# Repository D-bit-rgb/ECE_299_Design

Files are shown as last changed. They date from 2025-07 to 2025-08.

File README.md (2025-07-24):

# ECE 299 Final Project – FM Clock Radio Prototype

This repository contains the full documentation, code, schematics, and PCB layouts for a custom FM Clock Radio designed as the final submission for the ECE 299 course at the University of Victoria.

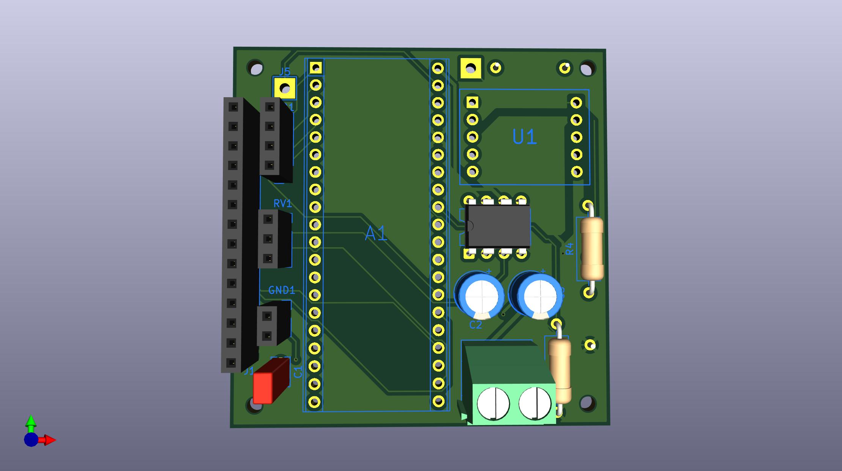
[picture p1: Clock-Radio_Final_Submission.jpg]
Final PCB Design


---

## 📻 Overview

The FM Clock Radio combines an embedded microcontroller, a digital FM tuner, and a custom-designed PCB to create a functional prototype. The device is powered by a Raspberry Pi Pico running MicroPython, enabling station tuning, audio output, and modular interfacing.

The final product includes:

- FM radio functionality via I2C
- Custom PCB designed in KiCAD
- Schematic documentation
- 3D printable housing (prototype stage)
- Expandability for clock/alarm integration

---

## 📁 Repository Structure

```bash
.
├── .vscode/                        # VSCode workspace settings
├── .micropico/                    # MicroPython config for Pico
├── Clock-Radio/                   # Final PCB folder (KiCAD files)
├── Clock-Radio_Final_Submission.jpg  # Image of final PCB layout
├── Clock-Radio_Prototype.jpg      # Render of 3D enclosure/prototype
├── ECE299_SCHEMATIC.pdf           # Main schematic overview
├── fm_radio.py                    # MicroPython FM radio driver
├── fm_radio (1).py                # Backup or variant of the radio code
├── Radio.kicad_pro                # KiCAD project file
├── Radio.kicad_sch                # Main circuit schematic (KiCAD)
├── Radio.kicad_pcb                # Final PCB layout (KiCAD)
├── Radio_Schematic_1.pdf          # Amplifier or supporting circuits
├── Radio_schematic_2.pdf          # Additional subsystems
├── Sheet1.SchDoc                  # Altium schematic (legacy or alternate)
├── LICENSE                        # MIT License
└── README.md                      # This file

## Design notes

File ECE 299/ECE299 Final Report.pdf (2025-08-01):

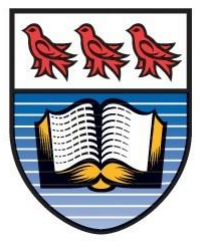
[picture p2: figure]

# ECE 299 Group 8 Final Project Report

## Daryon Ambasse – V01034226

## Rowyn Davis - V01038276

## Aug 2, 2025

# Executive Summary

This report outlines the ECE 299 final design project completed by students Daryon Ambasse and Rowyn Davis from May to August 2025. The course introduces students to the engineering design process through a term-long hands-on project, emphasizing planning, prototyping, testing, and documentation.

The project objective was to develop a functional clock radio system using a Raspberry Pi Pico W, programmed in Micropython. All time and radio data had to be displayed using dual SPI OLED screens, and a 2-layer custom PCB was required. The final product included a digital clock, alarm system, FM tuner, volume control, and world time zone viewer.

Key hardware components:

- Dual 128×64 OLEDs acting as one 256×64 display via SPI.
- FM radio receiver module (I²C-controlled).
- Alarm and snooze system with persistent flash storage.
- Amplifier and speaker system with volume potentiometer.
- 4 tactile buttons for user interaction across 5 modes.
- Custom 2-layer PCB with 0.6 mm traces for higher current paths.
- SolidWorks-designed 3D-printed enclosure with all I/O on one edge.

Software features included five interactive modes: clock display, radio interface, alarm setting, system info (12/24hr toggle), and time zone switching. The system used edge-detection for button presses, persistent JSON-based settings storage, and clean display updates in real time.

Throughout development, students learned soldering, PCB design, safe tool use, audio system optimization, and team-based project execution. Challenges such as broken displays, pin damage, and enclosure misfits were resolved through iterative testing and repair.

The project was delivered on time, under a $63.26 budget, and met all technical and functional requirements. It demonstrates practical application of embedded systems design, teamwork, and engineering professionalism aligned with EGBC standards.

## Table of Contents

# List of Tables

Table Number Title | Page number
Table 1 | Team Member 1, tasks and deliverables | 9
Table 2 | Team Member 2, tasks and deliverables | 10
Table 3 | Bill of Materials for entire project | 13

# List of Figures

Figure Number Title | Page number
Figure 1 | PCB Schematic | 12
Figure 2 | PCB editor layout in KiCAD | 15
Figure 3 | 3D PCB front view in KiCAD | 16
Figure 4 | 3D PCB back view in KiCAD | 17
Figure 5 | 3D Lid Back View in SolidWorks | 18
Figure 6 | 3D Lid Front View in SolidWorks | 18
Figure 7 | 3D Bottom Back View in SolidWorks | 19
Figure 8 | 3D Bottom Front View in SolidWorks | 19
Figure 9 | Lid Drawing in SolidWorks | 19
Figure 10 | Bottom Enclosure Drawing in SolidWorks | 19
Figure 11 | Terminal Output from button test in Appendix D | 21
Figure 12 | MP4 file of the speaker output using the radio test file in Appendix F (channel frequency 98.5) | 22
Figure 13 | Dual OLED test display as per Appendix E | 23

# Project Goals

The project goals that were agreed upon include:

1. Implement battery power using AA batteries to power the operation of the clock-radio system.
2. Enable user-adjustable clock and alarm settings, including the option to display alternate time zones.
3. Incorporate a snooze feature.
4. Provide intuitive FM radio channel selection through accessible user input.
5. Clear audio playback from a compact onboard speaker.
6. Display all relevant system information—including time, alarm status, FM channel, snooze, and alternate time zones—across two OLED screens using SPI communication.
7. Have an animal themed aesthetic by integrating a stuffed animal as the exterior.

8. Develop a structural “skeleton enclosure” using SolidWorks to support internal components and maintain structural stability.
9. Design a compact (<30 cm²) 2-layer PCB in KiCad that integrates both the Raspberry Pi Pico W and the audio amplifier circuit.
10. Utilize a maximum of four buttons and one potentiometer to manage all user interface settings and volume control.

# List of constraints

The constraints that were set out by the students and Prof. Ilamparithi Thirumarai Chelvan are as follows [2]:

1. Design and assemble the final clock/radio by July 29, 2025.
2. Only 1 Raspberry Pi Pico W is to be used as the microcontroller for all handling. Must be programmed with Micropython.
3. The clock displays radio and clock information. Communicates with the Raspberry Pi through SPI protocol.
4. The radio communicates with the Raspberry Pi through I2C protocol.
5. Design and manufacture an animal themed enclosure.
6. Team members must be from the same lab section.
7. Submit the final report by August 2, 2025.
8. This project will cost the students money.

# Project Expectations

The expectations set out for this project [2]:

1. Project Expectations:
a. Design and order a 2-layered PCB with a maximum footprint of 30cm².
b. Design and assemble an enclosure using SolidWorks.
c. Solder all the components to the ordered PCB.
d. Present the clock/radio in an animal themed/enclosure.
e. Display the finished project on July 29, 2025.
2. Clock/Alarm Expectations:
a. Be able to set clock/alarm time through user interface, either hardware (i.e., buttons) or software (i.e., a website).
b. Display time in 12- or 24- hour format.
c. Have the capability of displaying different time zones through hardware or software user interface.
d. Be able enable/disable the alarm through user interface.
e. Be able to set a snooze button for the alarm.
3. Radio Expectations:
a. Be able to tune to local FM radio channels through a user interface.

b. Play audio output through a speaker.
c. Be able to control the volume through a user interface.
d. Display the radio channel information to the user.

# Design Choices

1. Project Design Choices:
a. 2-layer PCB: The team chose to use a 2-layer PCB in KiCad with the dimensions of 5.45cm x 5.49cm (29.92cm²). Using a 2-layer design allowed us to solder components on both sides of the board, effectively doubling the usable surface area. This improved the design flexibility and helped support components being placed closer together. Using a 4-layered board would increase the advantages of the 2 layered board by allowing more dense traces to save more room, however, according to Texas Instruments “PCB Design Guidelines For Reduced EMI”, 2-layer boards can achieve 95% of the effectiveness of 4-layer boards so long as [3];
- Ground is routed underneath power.
- Grid power and ground but be careful to not create unneeded common impedance connections.
- Length-to-width ration should not exceed 3:1 for any traces between IC and ground voltage.
- Under the microcomputer (i.e., the Raspberry Pi Pico W), build a solid ground plane to limit the noise. (this couldn’t be done without compromising the <30cm² constraint).
- Route returns for direct connections to the processor I/O directly under the signal trace.
b. SolidWorks Enclosure Design: The enclosure was designed in SolidWorks to fit the electrical components (Raspberry Pi, PCB, Batteries… etc.) as well as mount the buttons and OLED screens. When designing the enclosure following the 3D-printing design rules set by HYDRA RESEARCH [4]. These include but are not limited to:
- Not having horizontal bridging no longer than 10mm without vertical supports,
- R > 4mm for base corner rounding,
c. Component Soldering: All through-hole components are soldered by hand using a temperature-controlled soldering iron, following the Kester Soldering process [5]:
- Apply heat to through-hole & component pin.
- Apply solder to through-hole & component pin.
- Remove solder first after a small drop has melted into the connection and then remove heat last.
d. Present the clock/radio in an animal themed/enclosure: According the set ECE299 project constraints [2], the clock/radio enclosure needs to be in an animal shape.
e. Display the finished project on July 29, 2025: According the set ECE299 project constraints [2], presentation of the finished clock/radio to the professor and lab TA will be conducted during the last week of labs (July 29, 2025, for Rowyn Davis and Daryon Ambasse).
2. Clock/Alarm Design Choices:
a. Be able to set clock/alarm time through user interface: Using the maximum allowed number of buttons, the team created an intuitive UI that allowed users to change the time for either the clock or alarm by having using the following buttons as specified:
- Button 1: Button 1 allowed for the change of “modes”. These modes included set time and set alarm. In each mode, the use of the following buttons changed.
- Button 2: Button 2 allowed for the change of either hour or minutes in the Set Time mode or enable/disable alarm function in the Set Alarm mode.
- Button 3: Button 3 added +1 to either the hour or minute in the Set Time mode and +1 hour in the Set Alarm mode.
- Button 4: Button 4 subtracted -1 from either the hour of minute in the Set Time mode and +1 minute to the Set Alarm mode.
b. Display time in 12- or 24- hour format: By cycling to “mode 3” titled “Info” the user can activate button 4 to switch between 12 to 24-hour formatting. The process works in the following way:
- Program reads the current set time and applies a modulo factor of twelve to the current hour.
- Check if the remainder is zero; if so, replace it with 12 (i.e., midnight or noon is displayed as “12” instead of “0”).
- Determine whether to display “AM” or “PM” by checking if the original hour is less than 12 (AM) or 12 or greater (PM).
- Display the formatted time with an “AM” or “PM” suffix if in 12-hour mode, or without suffix if in 24-hour mode.
- Save the user’s display format preference (12hr or 24hr) in settings. Json so the clock remembers it after reset or power loss.
- The setting toggles every time the select button is pressed while in mode 3, updating both the display and the saved file.
c. Displaying different time zones: By cycling to “mode 5”, titled “Time Zone”, the user can activate button 4 (select) to cycle through every global time zone from UTC−12 to UTC+14 (including half-hour and 45-minute offsets). The process works in the following way:
- A predefined list of tuples stores all 39 time zones in the format ("UTC±X", offset_in_minutes).
- When the user presses the select button in mode 5, a counter (tz_index) is incremented and wrapped around when it exceeds the list length.
- The current local time (set manually in time_set mode) is retrieved and converted to a UNIX timestamp.

- The program adds the selected offset (in minutes × 60 seconds) to the timestamp to simulate that time zone.
- The updated timestamp is passed to local_time () to format it into a readable time structure.
- The formatted time (respecting 12/24-hour display setting) is shown on the dual OLED screen along with the label (e.g., “UTC+5:30”).
- The selected time zone does not change the actual internal clock — it is purely for viewing other world clocks.
- When the device resets, it starts at the default time zone (usually UTC+0), unless extended to save the last used tz_index.
d. Be able to enable/disable the alarm through user interface: When the alarm is set using “mode 2” and activated, it will go off at the designated time and can be disabled or snoozed by user input. The process works in the following way:
- The user enters mode 2 and uses buttons 1 and 2 to set the desired alarm hour and minute values.
- Button 4 toggles the alarm between ON and OFF states. A visual confirmation is shown on the screen (e.g., “Alarm On”).
- The alarm settings are saved to a persistent file (settings. Json) so they remain after power loss or reset.
- In the main loop, the current time is compared with the stored alarm time once per second.
- When the time matches and the alarm is ON, alarm_active is set to True, and a visual notification (flashing display and message) begins.
- If the user presses button 4 (select) while alarm_active is True and the system is in mode 0 (default time mode), the alarm is deactivated for that session (i.e., alarm_active = False).
- Alternatively, a snooze function may delay the alarm by 5–10 minutes (if implemented with button 3, for example).
- The alarm will not trigger again until the time is set forward again, or the device is restarted (depending on snooze implementation).
e. Be able to set a snooze button for the alarm: While the alarm was on, users could press button 2 to start the snooze duration. How long the snooze lasted for could be set by the user by going to the Snooze mode (using button 1) and selecting anywhere from 0-30 mins.
3. Radio Design Choices:
a. Be able to tune to local FM radio channels through a user interface: Modifying the provided code from Exp. 3 [6], the team managed to connect and select specific channels.
- Using buttons 3 & 4, users could go up (+0.2MHz) or down (-0.2MHz) in frequency.

- The radio frequency would be displayed on modes “Change Radio” and “Clock”.
b. Play audio output through a speaker: Using the audio amplifier circuit in combination with RDA5807M module, LM386-4 audio amplifier, and I2C protocol, the received FM radio input was outputted to the 8Ω, 0.5W speaker.
c. Be able to control the volume through a user interface: Using a 0-200Ω potentiometer to control the input voltage from the Raspberry Pi to the audio amp circuit. This gives direct control from the user to the radio.
d. Display the radio channel information to the user: Using the code from Exp. 3 [7], users were able to display and play the wanted FM-radio (i.e., 101.9) to the OLED screen.

# Project Planning

The original project planning milestone designated team members roles and designations split between hardware and software, table 2 “Roles and Responsibilities” [2] shows the initial expectations of all members. these initial conditions laid the groundwork for assigning tasks based on team members skills and responsibilities. As per the project milestone report [2], team members set deliverable dates to complete the above tasks including testing and correcting the user experience. The following table demonstrates an accurate model of the tasks completed by team members and the effective date of delivery.

Team member 1: Daryon Ambasse
Task | Testing model | Date of delivery
Wire and test the FM receiver with a single button input. | Upload the provided radio initializer file from “Lab 3” [6] adding button capabilities to change the frequency by a factor of ±0.2MHz. Then updating the model to change volume on each button press. | June 12, 2025
Design and Manufacture PCB | Design the PCB to include: • Radio and Amplifier circuit with external speaker connection to the mounted 2 Position PCB Terminal Block. • External connection ports for dual-OLED screens. • External 5-volt power connections for proper distribution to V-BUS and V-SYS on the Raspberry Pi Pico W. • External connection points for four micro-pushbuttons. • Proper M3 sized holes for mounting on the enclosure. Upon completion of the design, fully test it on a breadboard to determine points of weakness or shorting in the circuit. | July 2, 2025
Build LM386 Amplifier circuit using KiCAD. | Design the amplifier circuit in KiCAD then verify using a breadboard. Confirm audio quality in ELW | July 25, 2025

| building to record how the signal is affected in a Faraday Cage, extend antennae accordingly to capture the frequency 101.9.
Provide initialization file to accommodate for an extended OLED screen using two smaller screens. | Use a daisy-chain method for shared MOSI and MISO connections to the screens with separate Chip select pins, creating an extended display. Test the extended display by placing text files in both screens and observing the effect of trying to display one image spanning both screens. | July 25, 2025
Soldering PCB components | Solder all through-hole components onto the PCB using a lead-free solder wire. | July 18, 2025

Table 1 - Team Member 1, tasks and deliverables

Team member 2: Rowyn Davis
Task | Testing model | Date of delivery
Design and 3D print the Enclosure | Design the enclosure to accomplish: • Design the top lid to mount dual-OLED screens, 4 buttons, and a potentiometer for user interface. • Design the bottom enclosure to hold and manage the custom designed PCB, Raspberry Pi Pico W, and 2 AA batteries. • Have enough structural stability to stand up on its own without any supports. • Add a hole for wires to connect from the mounted UI components and the PCB/Raspberry Pi. Upon 3D printing the enclosure, the corners and screw holes were carved and sanded. The UI components were added, and the full project was assembled and tested. | July 18, 2025,
Wire and Test User inputs | Mount and test button input (appendix D). | July 26, 2025
Soldering UI components | Soldered all needed connections (i.e., buttons, potentiometer…) using lead free solder wire. | July 28, 2025
Installation & Final Testing | Assemble and wire all connections for final presentation. Use testing files (appendixes D, E, and F) to inspect all functionalities. | July 29, 2025

Table 2 - Team Member 2, tasks and deliverables

# Circuit Design & Schematic

The following circuit integrates available hardware for a working clock-radio around a central Raspberry Pi Pico W microcontroller to implement a multi functional system. The schematic consists of the following subsystems:

- Dual display OLED system
- Two SSD1306 OLED displays (128 x 64 each) connected via SPI.
- Sharing MOSI and SCK lines.
- MOSI = GPIO-19.
- SCK = GPIO-18.
- Individually using separate Chip Select (CS) pins.
- Left display CS = GPIO-17.
- Right display CS = GPIO-05.
- Shared DC (GPIO-20) and RES (GPIO-21) lines for command data control and hardware reset.
- Finished product has the two screens interact as one extended display with a size of 256 x 64.
- User input using buttons and a potentiometer
- Four push buttons connected to GPIO pins 0 to 3 completing the following tasks:
- Mode cycling.
- Increment selection by +1.
- Decrement selection by -1.
- Activate/Select.
- Buttons are pulled to low by default and high when pressed.
- Rotary potentiometer [7] bridges the radio module and amplifier circuit to control volume by varying the voltage through the circuit.
- FM radio module
- Connected via I2C bus:
- SDA → GPIO 26.
- SCL → GPIO 27.
- Controlled with a custom Radio class (via Micropython).
- Allows tuning, scanning, and volume control through software interface.

### 4. Power management through external 5-volt connection or via USB

- Internal regulator on Pico supplies power to displays and buttons at a steady 3.3-volts.

All the above features were taken into consideration while designing the PCB, ensuring appropriate GPIO pin assignments, power distribution, and component placement to support dual SPI displays, I²C radio communication, button inputs, and future expandability. Signal traces were routed with attention to minimizing interference between high-frequency SPI lines and analog components like the potentiometer. Additional considerations included mounting hole placement for enclosure integration, silkscreen labels for easier debugging, and decoupling capacitors near ICs to ensure stable operation.

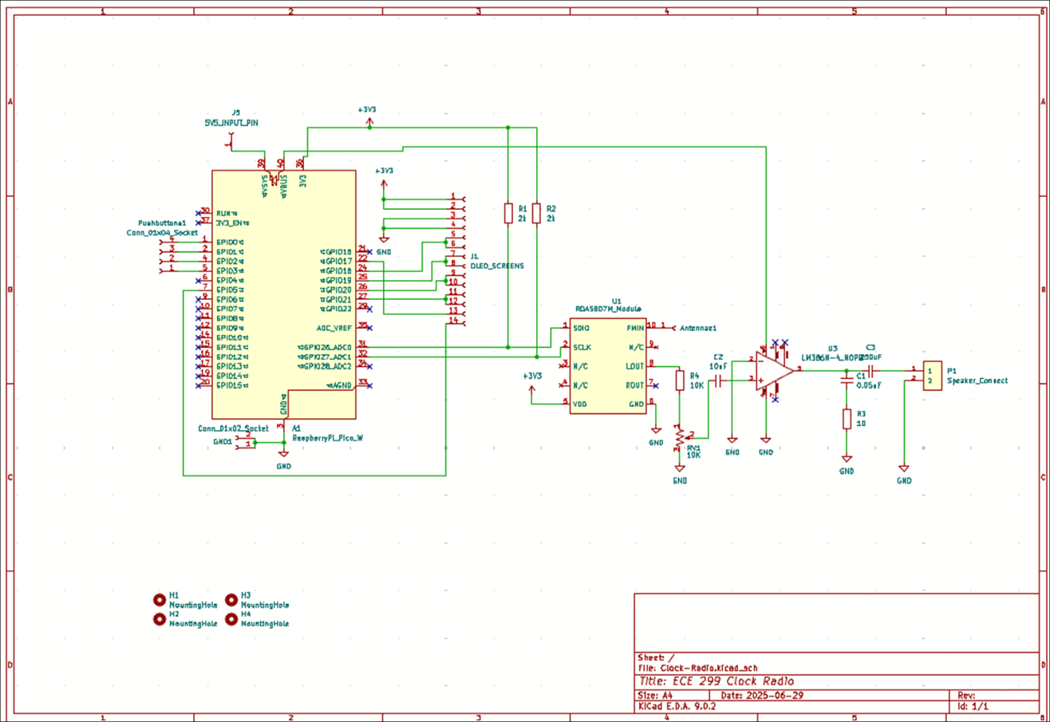
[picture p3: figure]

Figure 1 - PCB schematic

# Bill of Materials & Cost Analysis

Label in Schematic/Drawing | Component Description | Part Number | Unit Quantity | Cost per Unit | Source of Cost Information
Raspberry Pi Pico W | | | 1 | Free | ELW B320
GND_PIN | Ground test point on PCB | N/A | 1 | Free | JLC PCB
0.05uF | 50 nano-farad capacitors. | 399-9794-ND | 1 | Free | ELW B320
10uF | 10 micro-farad capacitors. | 493-13534-3-ND | 1 | Free | ELW B320
250uF | 470 micro-farad capacitors. | 493-1826-ND | 1 | Free | ELW B320
Conn_01x02_Socket | Socket headers for external ground connections. | 2057-PH1-07-UA-ND | 1 | Free | ELW B320
Mounting Hole | Mounting holes for M3 screws. | N/A | 4 | Free | JLC PCB
OLED_SCREENS | 1.3” OLED Display SPI | 1528-1512-ND | 2 | $4.00 | ELW B320
5V5_INPUT_PIN | 5-volt input test pad for external power supply. | N/A | 1 | Free | JLC PCB
Speaker Connect | 2 Position PCB panel mount | 2057-EBAA-02-C-ND | 1 | $1.50 | ELW B320
Conn_01x04_Socket | Pin header connections for buttons. | 2057-PH1-07-UA-ND | 1 | | ELW B320
2k | 2000-ohm resistor | 13-MFR-25FTF52-2KTB-ND | 2 | Free | ELW B320
10 | 10-ohm resistor | 2019-CF1/4CT52R100JCT-ND | 1 | Free | ELW B320
10K | 10000-ohm resistor | 2019-CFS1/4CT52R103JCT-ND | 1 | Free | ELW B320
10K | 10000-ohm potentiometer for user interface. | PTV09A-4020U-B103-ND | 1 | $1.00 | ELW B320
RDA5807M_Module | Through hole PCB mounted radio module. | RRD-102V2.0 | 1 | $2.00 | ELW B320
LM386N-4_NOPB | Through hole mounted audio amplifier unit. | LM386N-4/NOPB | 1 | $1.50 | ELW B320

Conn_01x14_Socket | Pin-header connections for externally connecting OLED screens. | 2057-PH1-07-UA-ND | 1 | $0.25 | ELW B320
Pushbutton Microswitch PCB | Microswitch pushbuttons for user interface. | 732-7004-2-ND | 4 | $0.25 | ELW B320
Speaker | External Speaker rated 2W/4Ω | 102-3546-ND | 1 | $4.00 | ELW B320
Monkey Stuffed Animal | Enclosure Exterior | N/A | 1 | $13.41 | Walmart
M2 Screw | | Rm2X8MM 2701 | 10 | $0.58 | Digikey
M3 Screw | | Rm3X6MM 2701 | 8 | $0.48 | Digikey
M6 Screw | | 770-270 | 5 | $0.99 | Digikey
Conn_01x_05_Socket | 5 position socket headers | 2057-PH1-07-UA-ND | 2 | $0.50 | ELW B320
Enclosure Manufacturing | Internal SolidWorks design for the monkey stuffed animal | N/A | 1 | $15.00 | UVIC Digital Scholarship Commons

Table 3 – Bill of Materials for entire project

# PCB Design

The custom PCB was designed to meet specific functional and physical constraints critical to the success of the clock radio project. The total board area was kept under 30 cm² to ensure compactness and compatibility with the planned enclosure. Four mounting holes, one at each corner, were included to facilitate secure installation. A key design consideration was preserving the clearance zone around the Pico W’s internal antenna; no traces or copper pours were routed in this region to prevent interference with wireless communication. To accommodate higher current demands, 0.6 mm wide traces were used for both the 5V power lines and the connections to the speaker output. Finally, to reduce wiring complexity and improve assembly and debugging, all external connectors were positioned along one edge of the board. This deliberate layout minimizes internal wire clutter and supports clean integration within the final device enclosure.

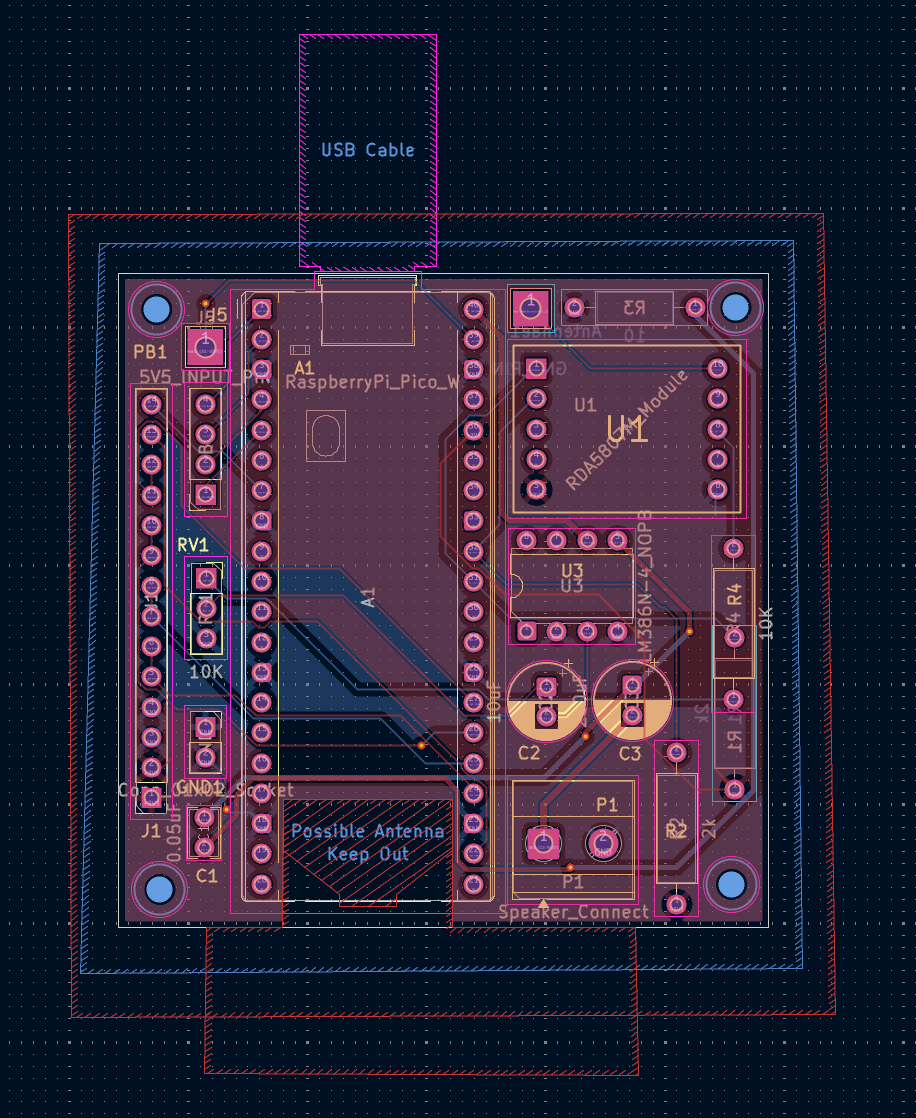
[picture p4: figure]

Figure 2 - PCB editor layout in KiCAD

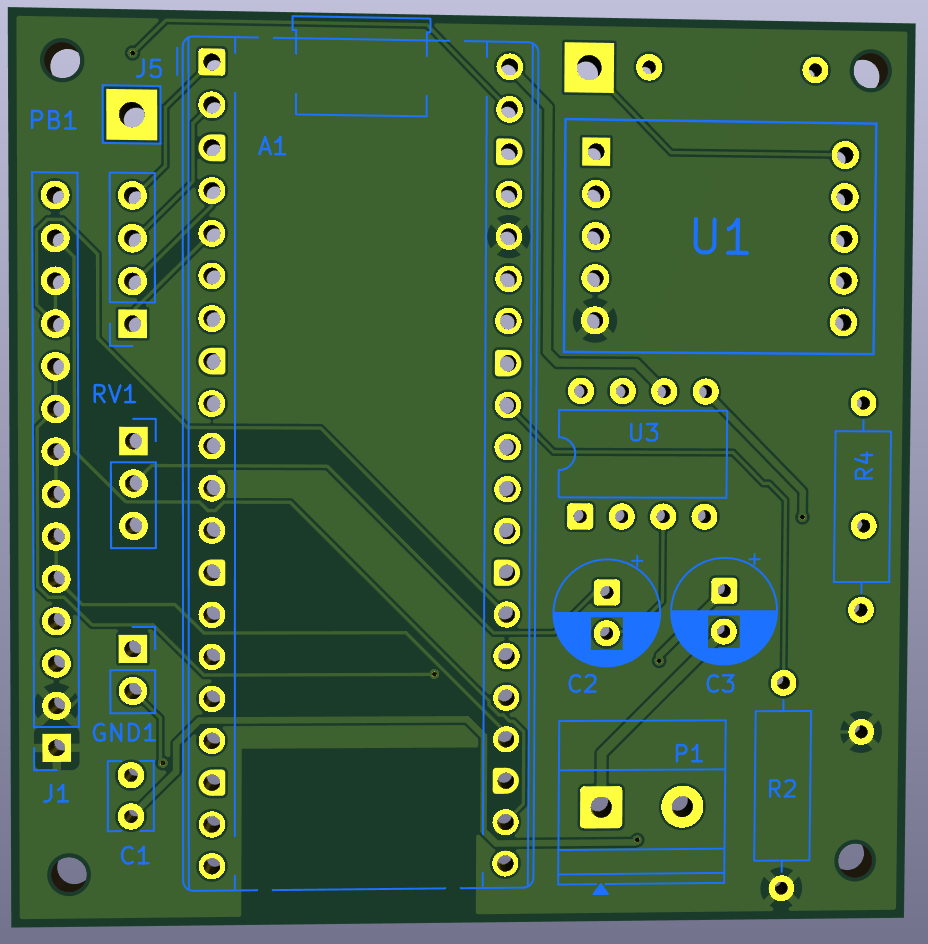
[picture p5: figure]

Figure 3 - 3D PCB front view in KiCAD

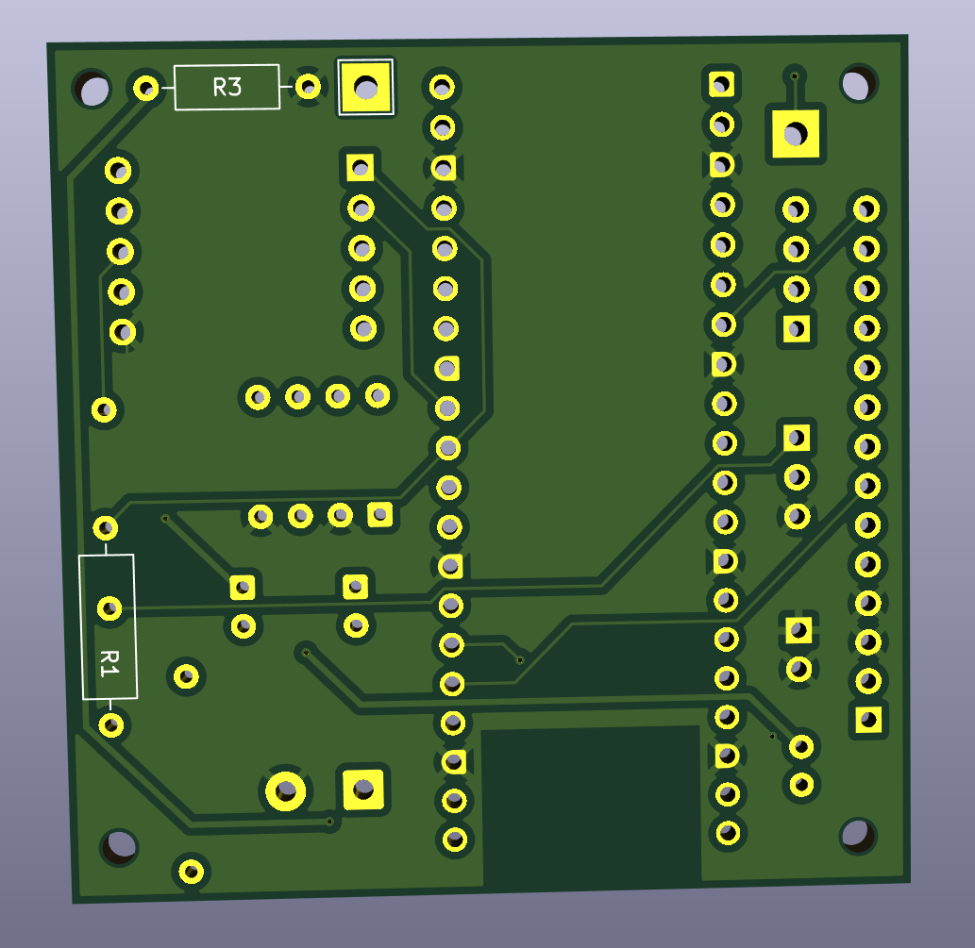
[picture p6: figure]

Figure 4 - 3D PCB back view in KiCAD

# Enclosure Design

The 3D-printed enclosure was designed to be the internal “skeleton” structure of the clock/radio. To keep the design choice of using a stuffed animal as the outer appearance, the internal enclosure needed to achieve the following:

- Be compact enough to be hidden inside the stuffed animal.
- Have purposeful built mounts for the 2 OLED screens and buttons.
- Hold the custom designed PCB and batteries in an easily reachable position.
- Have the bottom enclosure be heavy enough to act as a weight to keep the whole structure upright.

The lid was the best place to mount the screens and buttons. Special consideration was given to ensure that the neck was narrow but still strong enough to easily hold the weight of the screens. The button mount was designed to have 2 vertical supports (following the HYDRA RESEARCH guidelines [3]). Eight M3 screws were used to hold the OLED screens and four M6 screws to hold the lid to the bottom enclosure.

The bottom enclosure was designed with the intention of holding all the electrical components. Since the PCB had 2 layers, the team created 4 mounting points that could accommodate M2 screws to keep the board in place. They also added room for the batteries to be connected, leaving enough wires to be connected safely inside. A hole was placed in one of the walls for the connection wires from the PCB and Raspberry Pi to be connected to the external components (OLED screens, buttons, and speaker). Since the bottom was used as a counterweight, extra material was used to ensure that the whole clock/radio wouldn’t tip over.

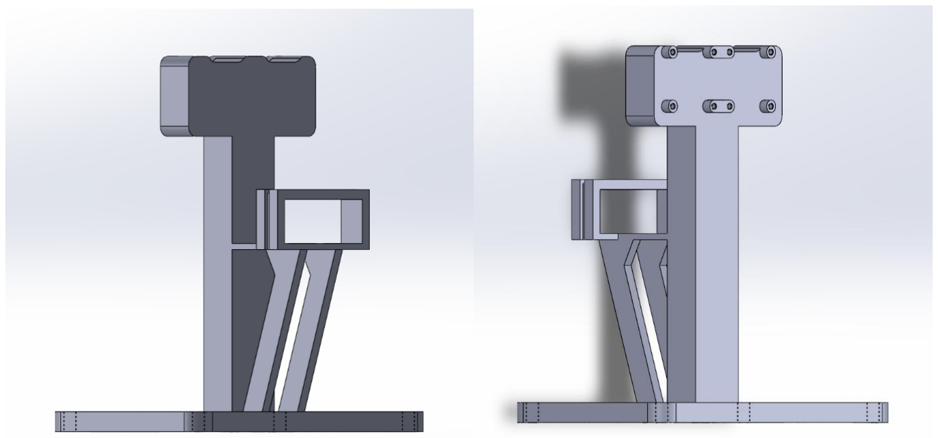
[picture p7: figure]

Figure 5 - 3D Lid Back View in SolidWorks | Figure 6 - 3D Lid Front View in SolidWorks

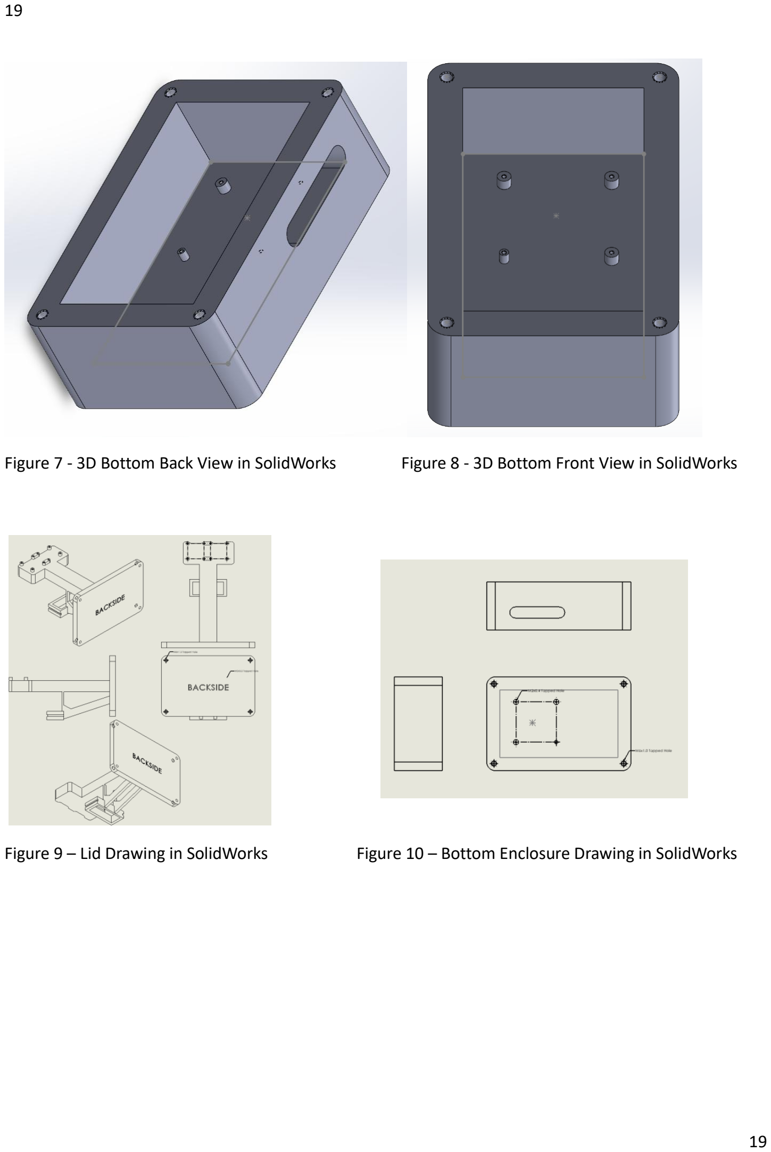
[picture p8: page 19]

Figure 7 - 3D Bottom Back View in SolidWorks | Figure 8 - 3D Bottom Front View in SolidWorks
Figure 9 – Lid Drawing in SolidWorks | Figure 10 – Bottom Enclosure Drawing in SolidWorks

# Testing & Validation

## Test Procedure 1 – Button Test (Appendix D):

Throughout the assembly of the clock/radio, there were multiple times where the user interface wouldn’t respond to button inputs. To troubleshoot this, the team developed a button test file that would see whether the problem came from the buttons/physical wiring or from the main.py file itself. The code itself worked by whenever a button is pressed when the code is running, the terminal on the laptop will print out which button was pressed. This helped troubleshoot if the buttons could be detected and if not, then the problem lied in the hardware/physical wiring.

Test Steps:

1. Load the Button Test code onto the Raspberry Pi Pico W using a micro-USB cable.
2. Run code and push wanted button(s).
3. Check terminal on laptop and see if the pressed button(s) are detected. The two possible outcomes are:
a. The pressed button(s) is detected: The terminal prints out “Button X pressed”. This means that the buttons are detected by the Raspberry Pi and that the problem lies somewhere in the clock/radio code.
b. The pressed button(s) is NOT detected: The terminal will not print out anything. This means that the problem lies in the hardware and could be a loose connection or a soldered point breaking.

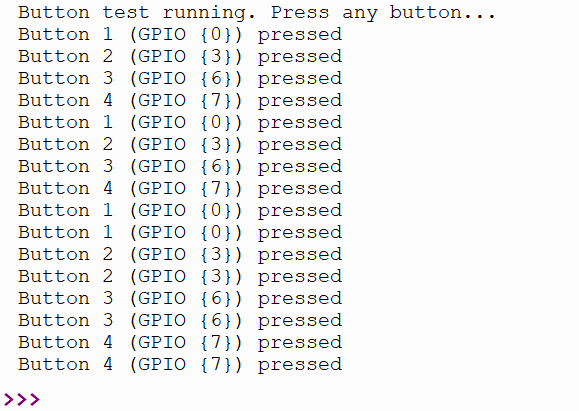
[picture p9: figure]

Figure 11 – Terminal Output from button test in Appendix D

The results above proved that the system was able to read button inputs from the user and was used to determine a pin issue from the board on GPIO-1 and GPIO-2 since they would automatically read high and wouldn’t change. This issue was solved by re-routing buttons three and four to GPIO-6 and GPIO-7.

## Test Procedure 2 – Radio Test (Appendix F):

Since the audio circuit is crucial to the working of the Clock/Radio, developing a radio test was important to determine the functionality of the whole project. Using the code from Exp. 3 [6] (which we know works), again using deductive reasoning to decide whether the problem lies in the circuit (if the code still does not work), or if the problem lies in our code.

Test Steps:

1. Load the radio test code onto the Raspberry Pi.
2. Connect to any local channel (i.e., 101.9 or 98.5 FM).
a. If no audio plays, then the fault lies in the hardware. The team can then pinpoint where the signal stops using a multimeter.
b. If audio does play, then the fault lies in the radio portion of the code and can be fixed.

20250728_152111.mp
4 (https://youtube.com/shorts/LLetZ34Rl4w?feature=share)

Figure 12 – MP4 file of the speaker output using the radio test file in Appendix F (channel frequency 98.5)

From the above figure it can be observed that the audio being produced by the radio module is clear and works as intended by the uploaded code. Afterwards all that is required would be to integrate with the dual OLED code and buttons to give the user complete control over the functionality of the clock-radio. Due to formatting if the video is inaccessible through the above “Figure 12” then please select the following link: Online Test Link. (https://youtube.com/shorts/LLetZ34Rl4w?feature=share)

## Test Procedure 3 – Dual OLED Screen Test (Appendix E):

Due to the way the team wanted to present information to the user, it was feasible to utilize two screens as one extended display rather than a single larger screen. After developing the initialization file, which can be found in Appendix C, it was necessary to test how information would display to the user. The team used the following logic to determine the necessary changes to be made before running our main project file (Appendix A):

Test Steps:

1. Determine the range where text would appear on either screen one or two.
2. Run some random text onto each screen to determine the pixel boundary between screens.
3. Try and run text across both screens to find any breaking point/places where text would cut out and be lost.

a. If text can be seen across both screens, then upload the main file and test the refresh rate of the clock along with button inputs.
b. If text is lost or cannot be displayed then update the initializer file, or a connection issue may be present between the shared MOSI and MISO pins on the Raspberry Pi.

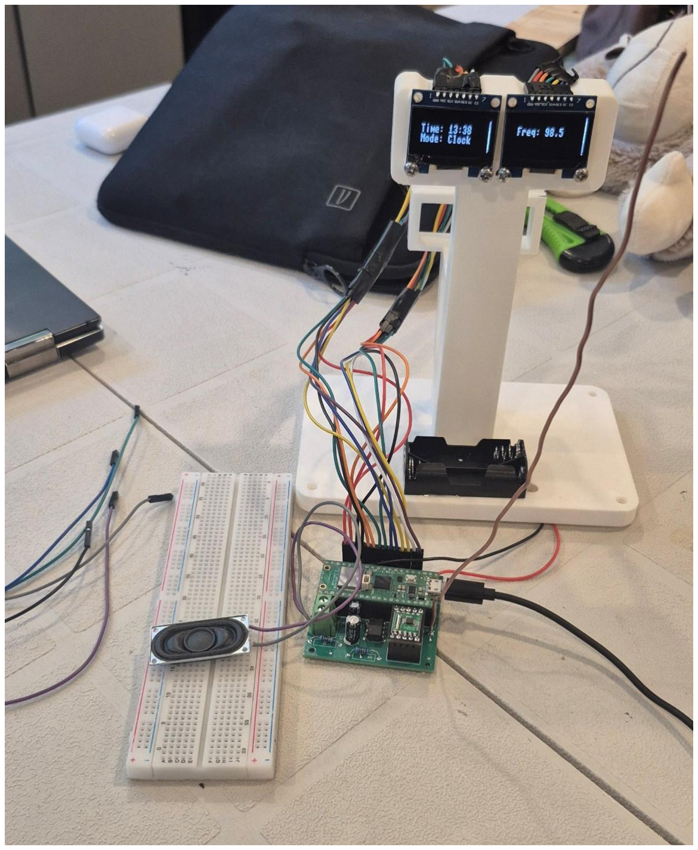
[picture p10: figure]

Figure 13 – Dual OLED test display as per Appendix E

As per the figure above it can be seen that the screen is displaying the Micropython code in Appendix E. This proves that both screens are interfacing with each other to create one larger extended display since the only difference in the texts being displayed are their positioning. This allowed the team to fully integrate display features into the main file knowing that the refreshed content would be properly updated and displayed without a loss of data.

# Code of Ethics

List the relevant code of ethics of EGBC and describe how you have
followed the relevant codes in your project

The relevant list of ethics pertaining to this project include the following from the registered EGBC “Code of Ethics” [8]:

1. Hold paramount the safety, health, and welfare of the public, including the protection of the environment and the promotion of health and safety in the workplace.

The team prioritized safe electrical design practices, ensuring that all power lines and components were selected within safe operating limits. Proper PCB trace widths were used for higher current paths, and all connections were insulated and tested to minimize the risk of electrical hazards during operation.

2. Practice only in those fields where training and ability make the registrant professionally competent.

The project was conducted strictly within the domain of Electrical and Computer Engineering, leveraging knowledge gained through coursework, specifically ECE 299: Electrical Design, which provided us with the relevant training in circuit design, PCB layout, and embedded systems development.

### 3. Provide accurate information in respect of qualifications and experience

All project documentation, including the Bill of Materials (BOM), schematic diagrams, and 3D models of both the PCB and enclosure, were created and presented with transparency and accuracy. Each figure was appropriately labelled and referenced to reflect our actual design and implementation.

4. Undertake work and documentation with due diligence and in accordance with any guidance developed to standardize professional documentation for the applicable profession.

The team applied a methodical and detail-oriented approach throughout the design, testing, and reporting phases of the project. Schematics and PCB layouts followed industry standards for clarity and reproducibility, and design files were reviewed and verified by group members before submission.

5. Conduct themselves with fairness, courtesy, and good faith towards clients, colleagues, and others, give credit where it is due and accept, as well as give, honest and fair professional comment.

Collaboration was central to our project. All team members contributed equally, and credit was given accordingly. Feedback was exchanged respectfully during design reviews, and any constructive criticism was received in the spirit of continuous improvement.

# Conclusions & Recommendations

Over the course of this project, the team gained valuable hands-on experience and developed critical engineering competencies through iterative design, testing, and problem-solving. Key technical skills acquired include proper soldering techniques for both surface-mount and through-hole components, machine-level programming using Micropython, and the successful implementation of an extended OLED display using custom SPI initialization routines. The team also became proficient in managing embedded audio output through speaker optimization, wire splicing for reliable power and signal delivery, and safe operation of power tools for enclosure fabrication. Additionally, the team strengthened their ability to manage time and distribute workload effectively within a high stress environment, which was crucial for synchronizing hardware and software integration across subsystems.

Despite the teams’ achievements, they encountered several challenges that tested their ability to adapt and troubleshoot under pressure. Critical issues included physical hardware failures such as screen fractures and battery ruptures, enclosure misalignment due to dimensional inaccuracies, radio interference issues likely stemming from poor shielding or grounding, code integration errors preventing successful compilation, and instances of short or disconnected wires affecting power and signal continuity. Furthermore, the team observed hardware degradation such as broken microcontroller pins due to repeated handling during prototyping.

To improve future iterations of the design, the team has compiled the following actionable recommendations based on their observations:

- Connect the potentiometer to an additional GPIO pin to record and display live volume levels on the OLED interface.
- Replace the traditional push-button system with a rotary encoder to reduce overall hardware complexity and improve user interface design.
- Begin debugging procedures earlier in the development timeline to identify electrical and software inconsistencies before integration.
- Conduct comprehensive tests on all subsystems independently, including multi-I2C initialization and display handling.
- Invest more time in familiarizing ourselves with advanced features of Micropython and embedded libraries relevant to real-time system control.
- Schedule regular technical consultations with lab technicians to receive timely feedback on circuit design and implementation practices.

- Ensure all custom enclosure manufacturing is completed by a vetted supplier to avoid delays and improve dimensional precision for mounting PCBs and displays.
- Perform rigorous power supply testing under different load conditions to prevent battery leakage, overheating, or explosion.

Through the successes and setbacks of this project, the students gained a deeper understanding of embedded systems development and the importance of iterative design practices. These lessons will be directly applicable to future engineering projects, particularly those involving complex hardware-software integration, user interfaces, and embedded control systems.

# Bibliography

[1] “ECE 299 Outline.” Accessed: Jul. 30, 2025. [Online]. Available: https://heat.csc.uvic.ca/coview/course/2021051/ECE299
[2] “Project expectations and marking scheme - Summer 2025 ECE 299 A01 (30279).” Accessed: Jul. 30, 2025. [Online]. Available: https://bright.uvic.ca/d2l/le/content/410580/viewContent/3301080/View
[3] Texas Instruments, “PCB Design Guidelines for Reduced EMI,” SZZA009. [Online]. Available: chrome-extension://efaidnbmnnnibpcajpcglclefindmkaj/https://www.ti.com/lit/an/szza009/szza009.pdf
[4] “Design Rules & Best Practices for FFF 3D Printing,” Hydra Research. Accessed: Jul. 30, 2025. [Online]. Available: https://www.hydraresearch3d.com/design-rules
[5] M. Kaminsky, “Hand Soldering Short Course.” Accessed: Jul. 25, 2025. [Online]. Available: www.kester.com
[6] “ECE299_Lab_Manual - updated on June 12 - Summer 2025 ECE 299 A01 (30279).” Accessed: Jul. 30, 2025. [Online]. Available: https://bright.uvic.ca/d2l/le/content/410580/viewContent/3338370/View
[7] “ptv09-potentiometer-datasheet - Summer 2025 ECE 299 A01 (30279).” Accessed: Jul. 30, 2025. [Online]. Available: https://bright.uvic.ca/d2l/le/content/410580/viewContent/3336401/View
[8] “Code of Ethics.” Accessed: Jul. 30, 2025. [Online]. Available: https://www.egbc.ca/complaints-discipline/code-of-ethics/code-of-ethics
[9] “MicroPython - Raspberry Pi Documentation.” Accessed: Jul. 30, 2025. [Online]. Available: https://www.raspberrypi.com/documentation/microcontrollers/micropython.html
[10] “Pico-W-datasheet - Summer 2025 ECE 299 A01 (30279).” Accessed: Jul. 30, 2025. [Online]. Available: https://bright.uvic.ca/d2l/le/content/410580/viewContent/3312758/View
[11] “Connecting-to-the-internet-with-pico-w - Summer 2025 ECE 299 A01 (30279).” Accessed: Jul. 30, 2025. [Online]. Available: https://bright.uvic.ca/d2l/le/content/410580/viewContent/3312759/View
[12] “audio-amplifier-lm386-datasheet - Summer 2025 ECE 299 A01 (30279).” Accessed: Jul. 30, 2025. [Online]. Available: https://bright.uvic.ca/d2l/le/content/410580/viewContent/3314237/View
[13] “Introduction to SPI Interface | Analog Devices.” Accessed: Jul. 30, 2025. [Online]. Available:
https://www.analog.com/en/resources/analog-dialogue/articles/introduction-to-spi-interface.html
[14] “ECE Kicad Libraries - Summer 2025 ECE 299 A01 (30279).” Accessed: Jul. 30, 2025. [Online]. Available: https://bright.uvic.ca/d2l/le/content/410580/viewContent/3342363/View

# Appendices

## Appendix A: Main project code for clock-radio functionality

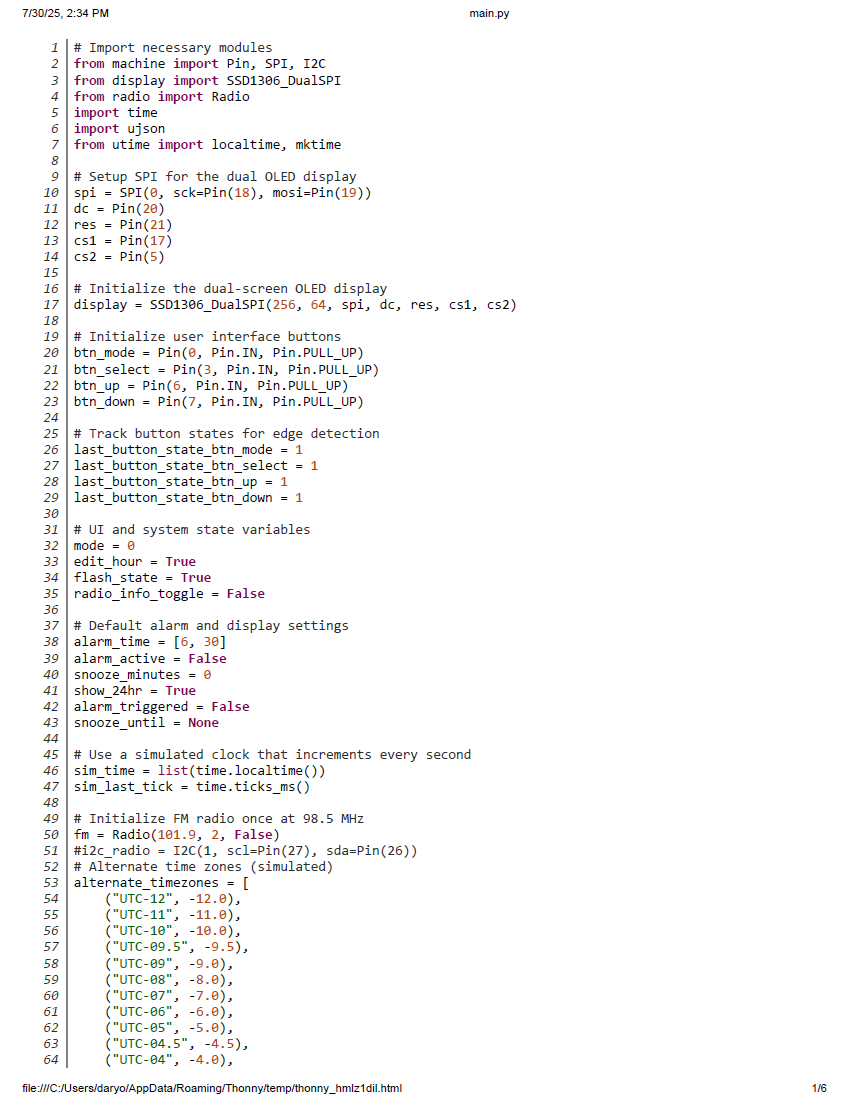
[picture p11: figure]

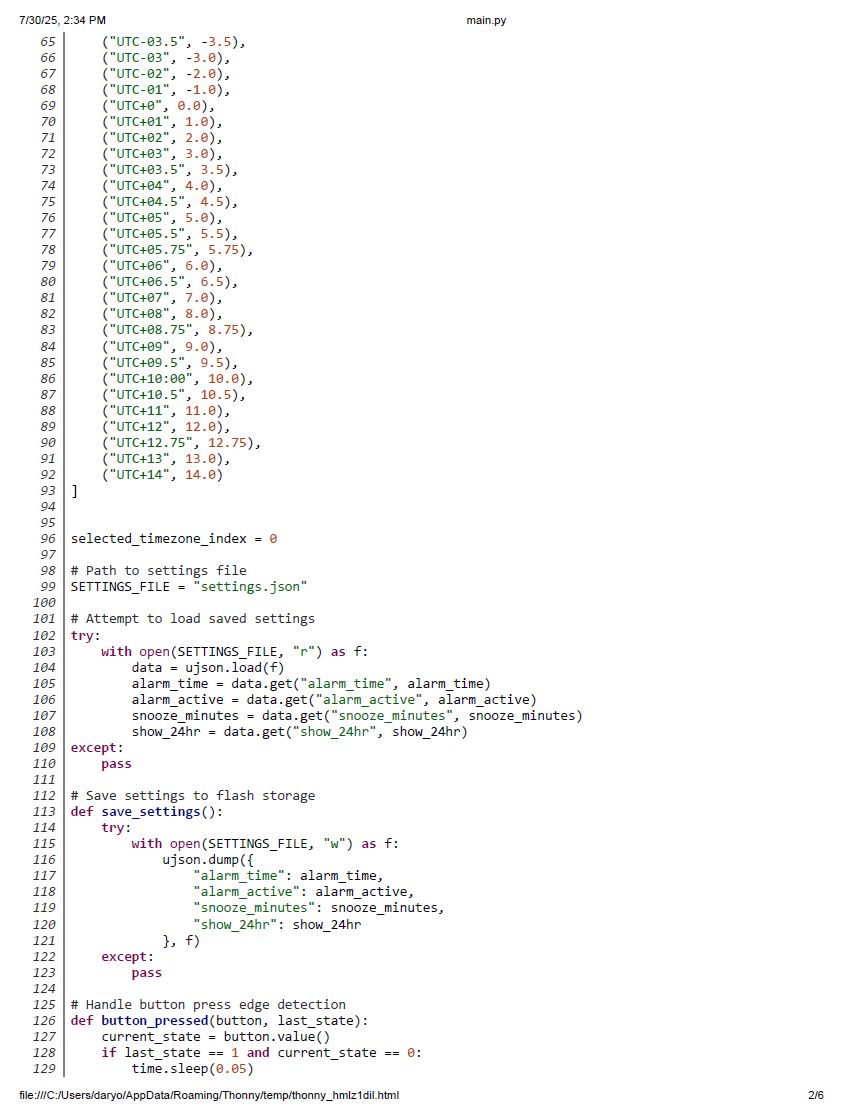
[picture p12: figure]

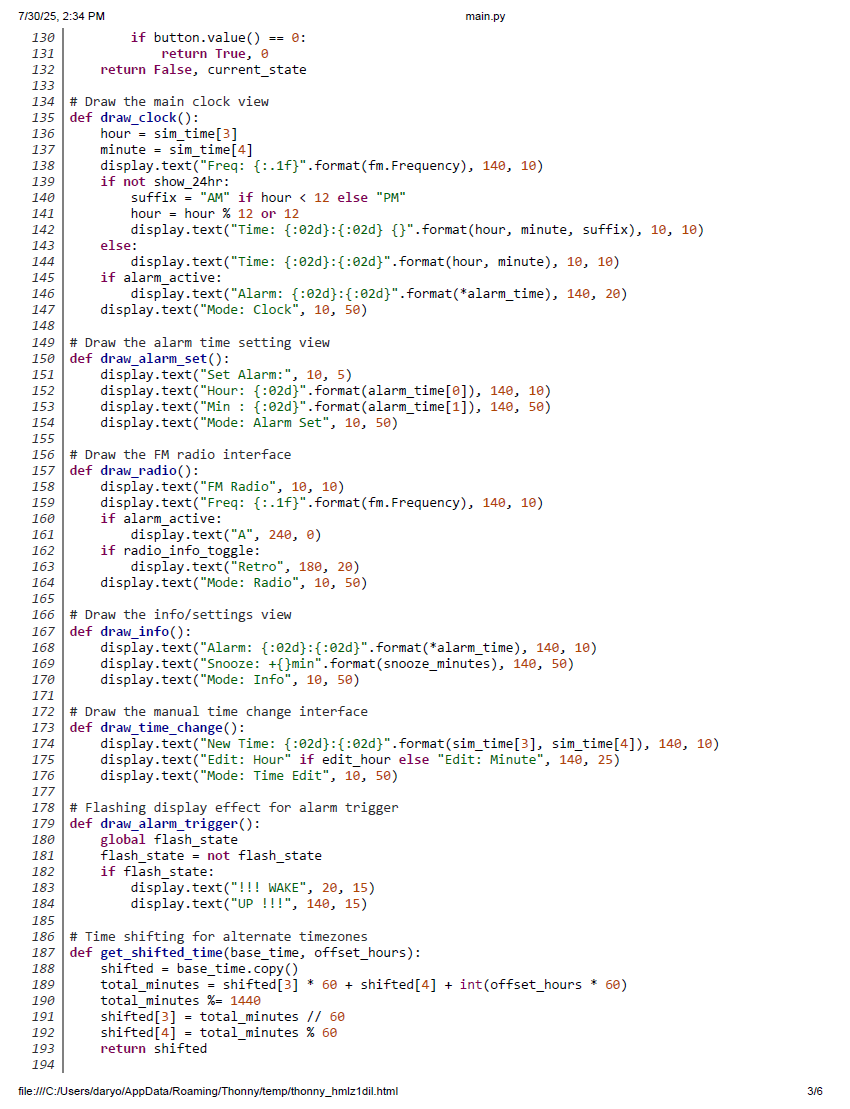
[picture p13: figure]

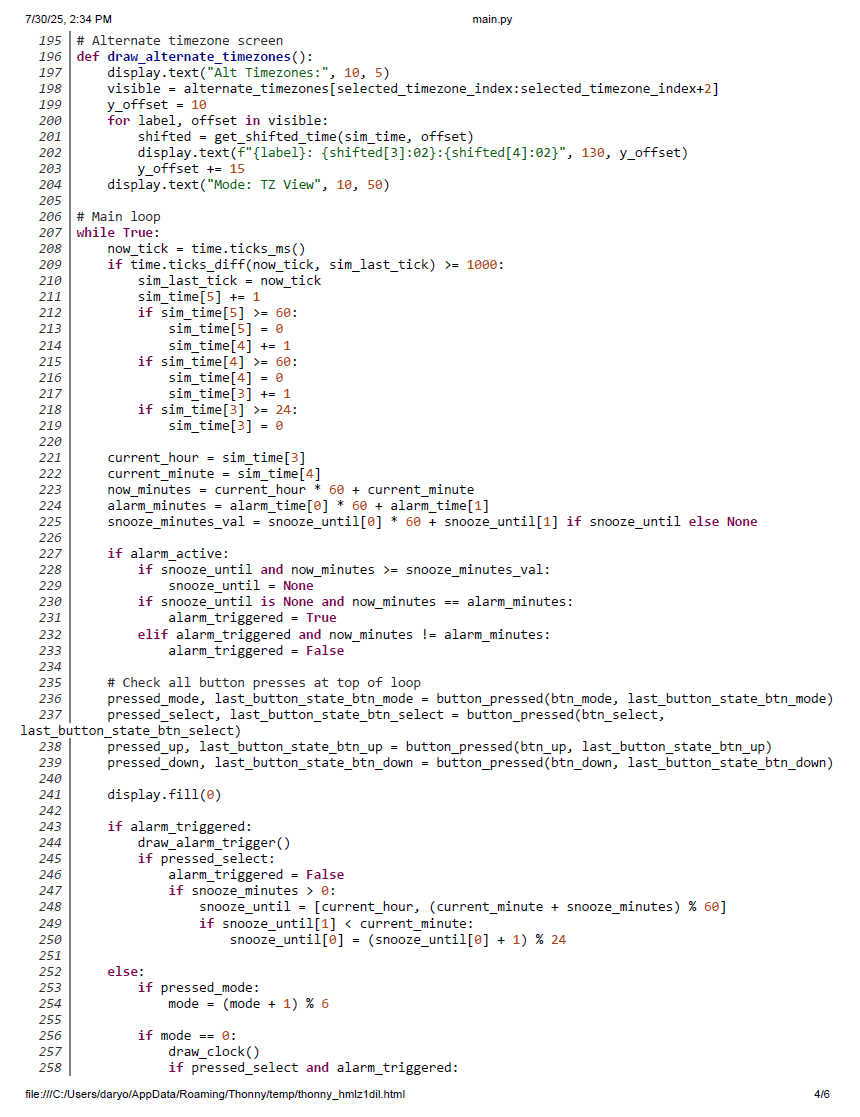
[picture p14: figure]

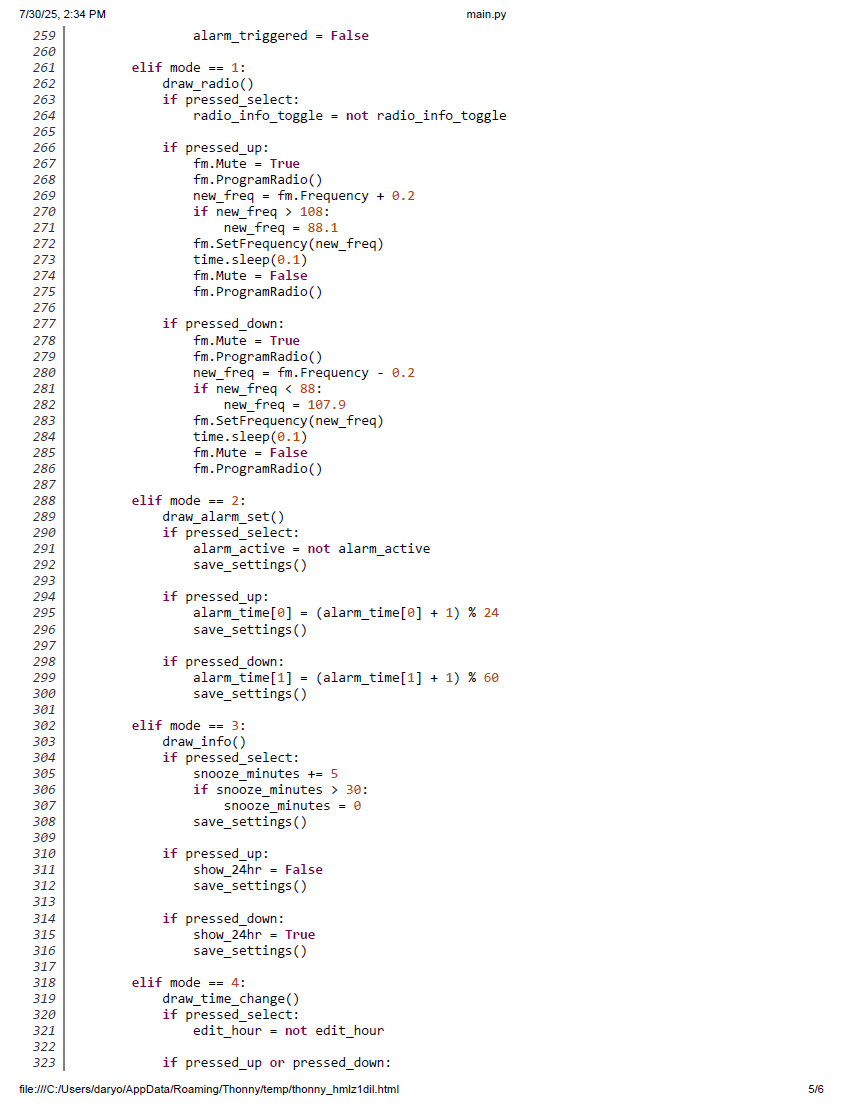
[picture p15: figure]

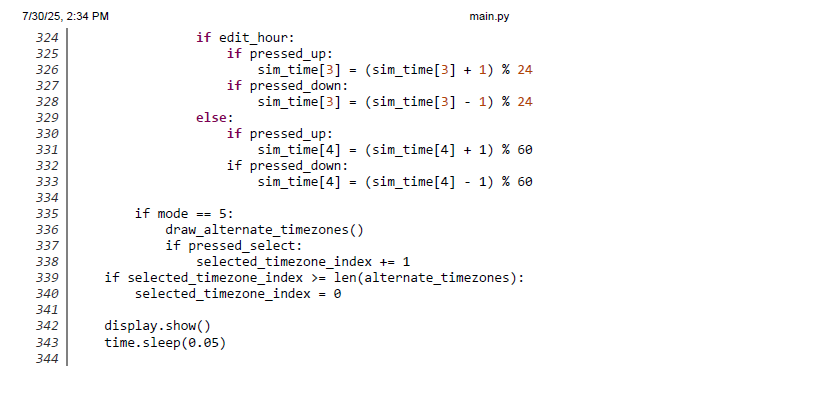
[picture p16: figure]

## Appendix B: Radio initialization

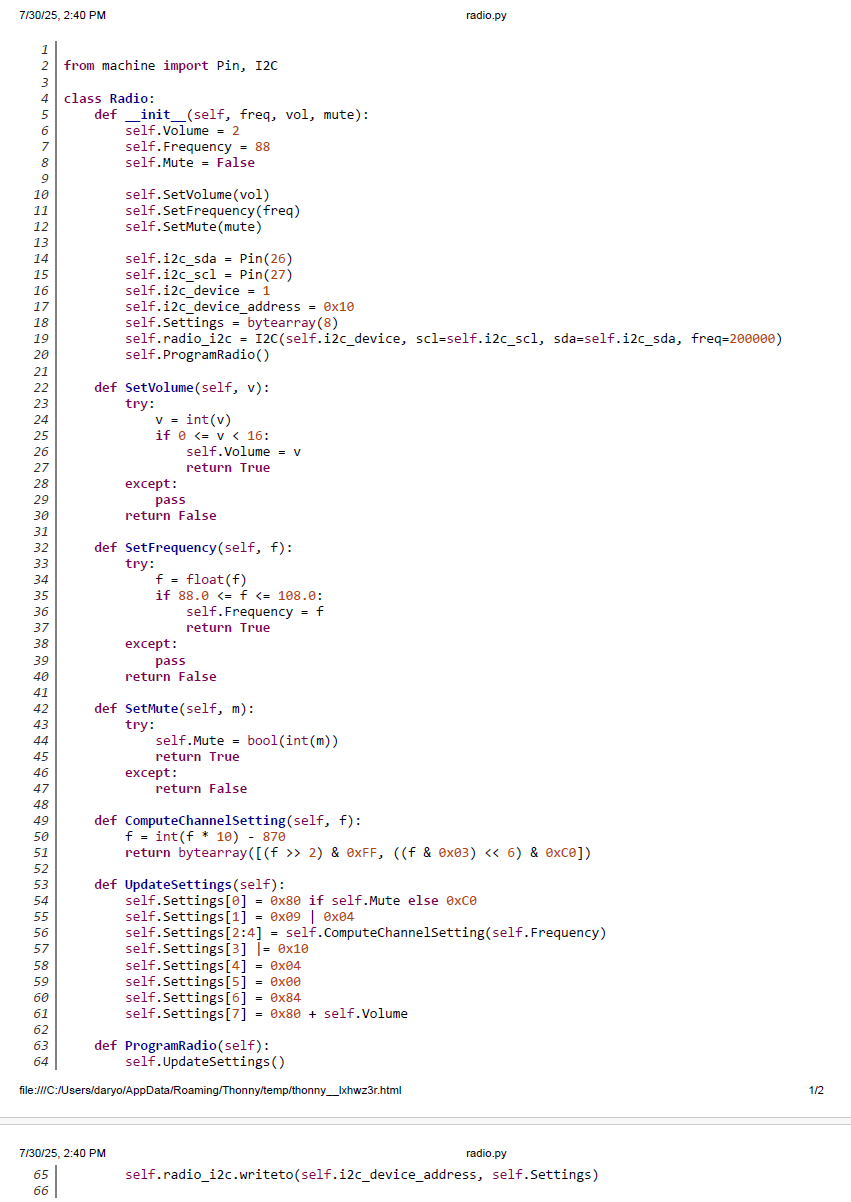
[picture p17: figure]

## Appendix C: Dual OLED Screen Initialization

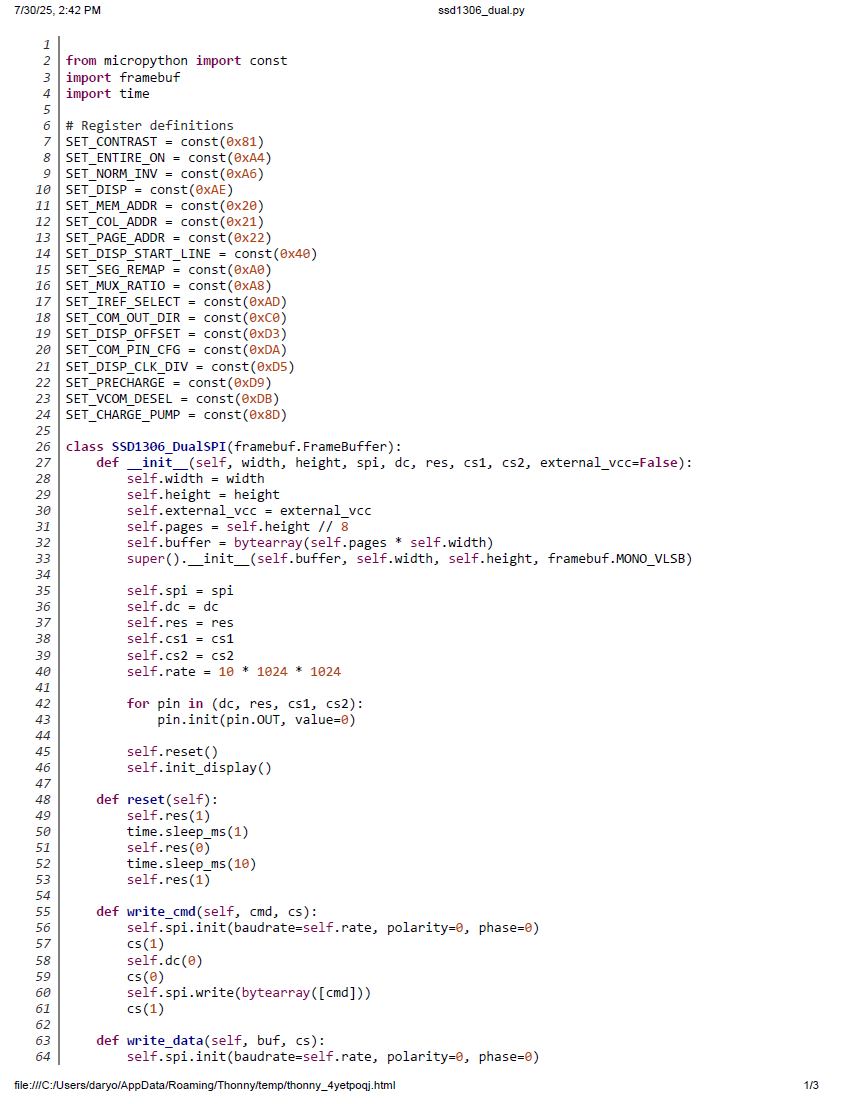
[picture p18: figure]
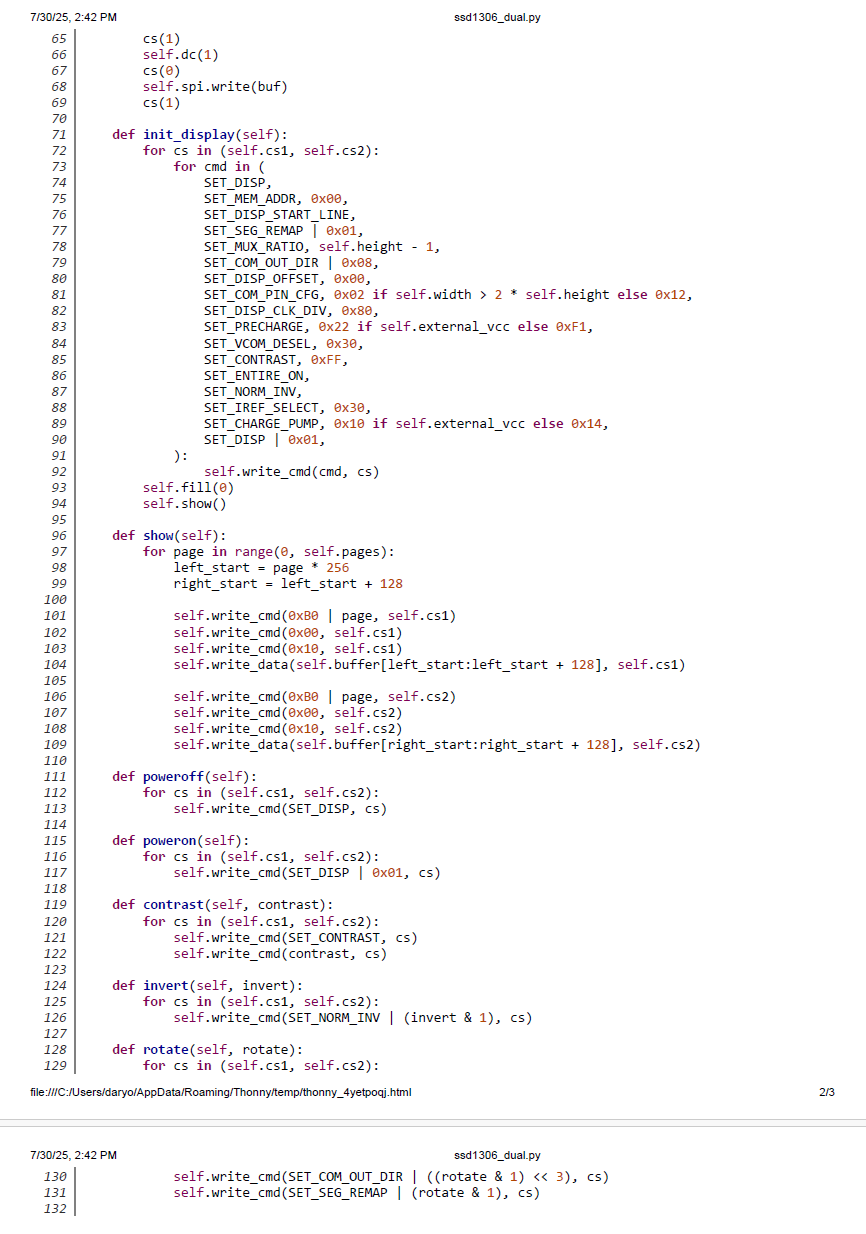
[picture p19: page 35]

## Appendix D: Button Test

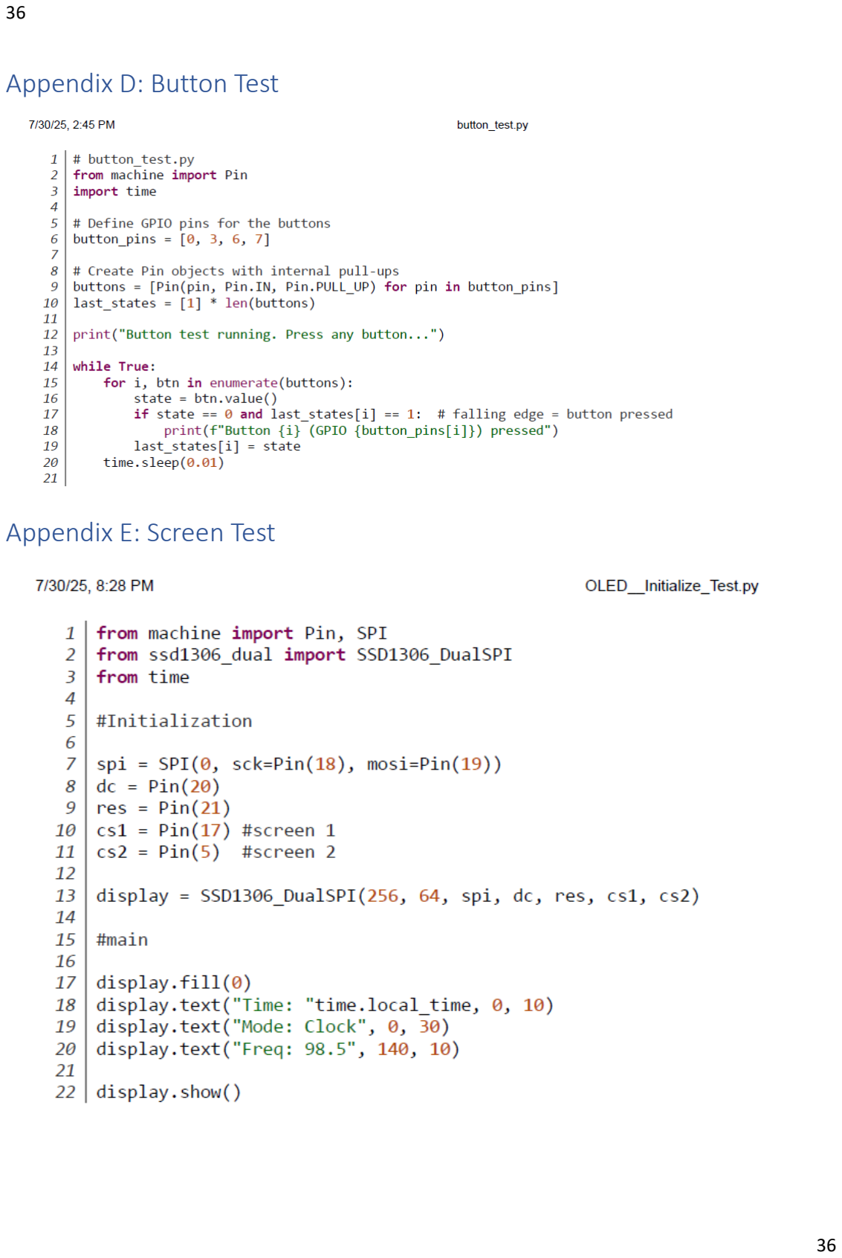
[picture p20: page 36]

## Appendix E: Screen Test

## Appendix F: Radio Test

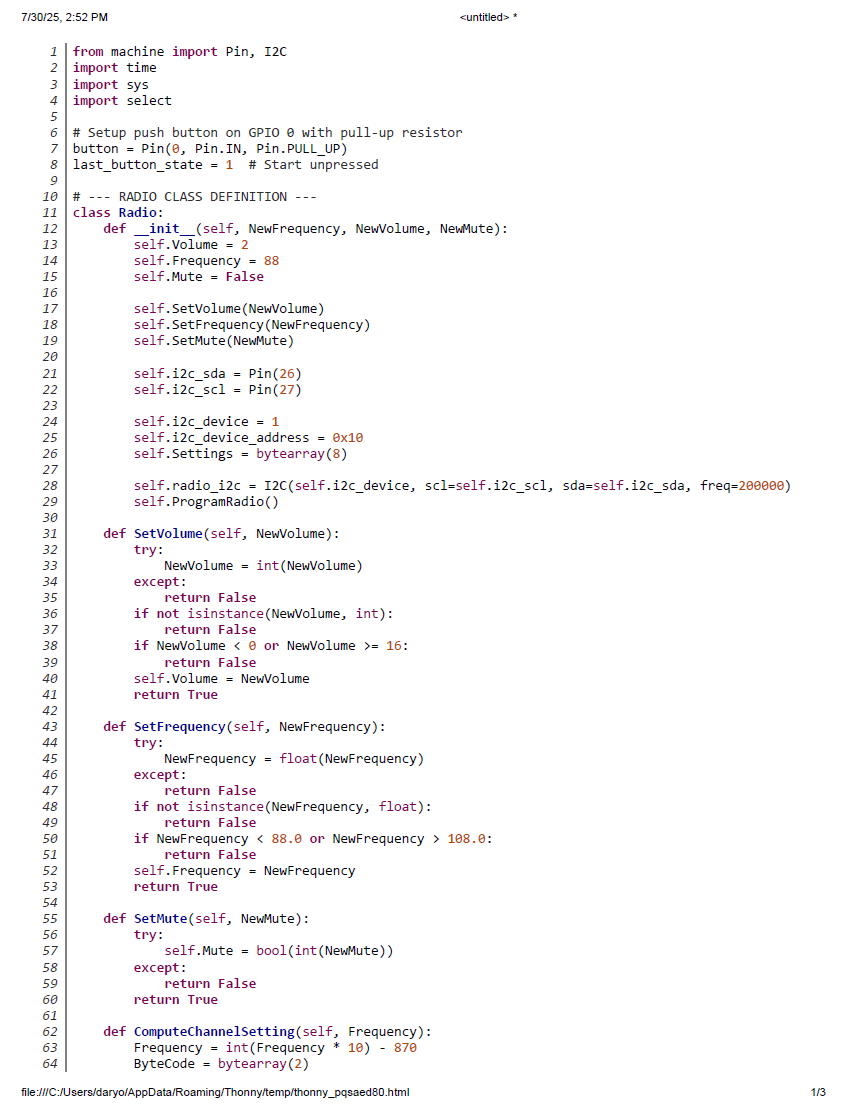
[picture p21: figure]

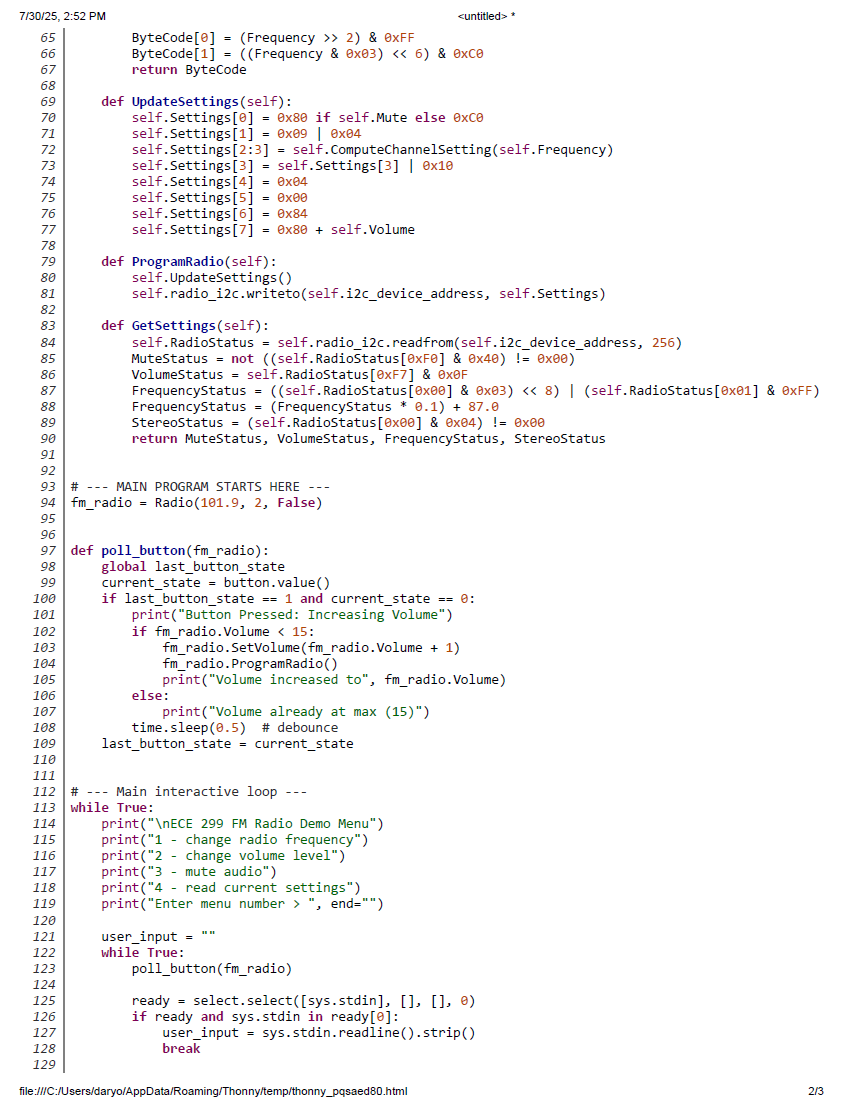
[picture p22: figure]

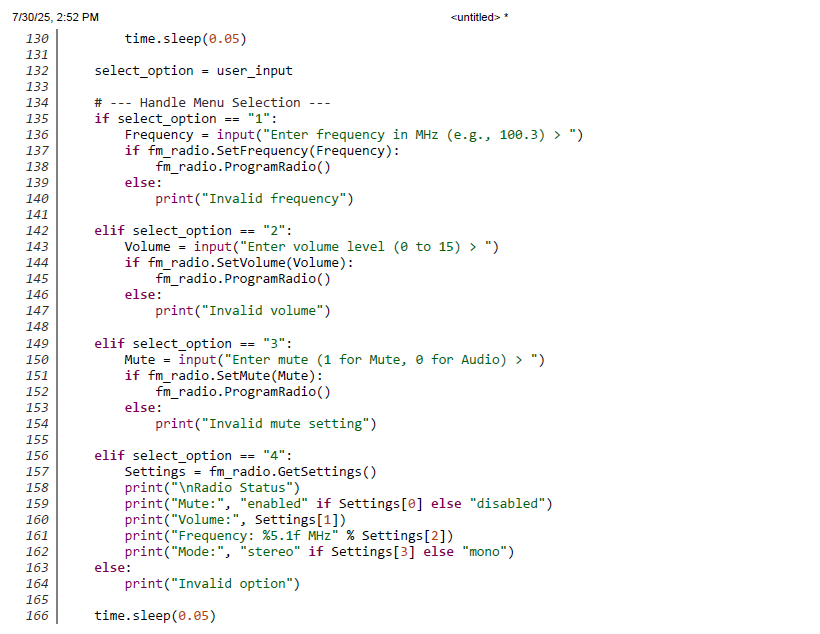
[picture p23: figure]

# Checklist

Final-report-checklist (https://uvic-my.sharepoint.com/personal/dambasse_uvic_ca/Documents/Final-report-checklist.docx?web=1)

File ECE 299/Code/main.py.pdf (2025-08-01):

1 | # Import necessary modules 2 | from machine import Pin, SPI, I2C 3 | from display import SSD1306_DualSPI 4 | from radio import Radio 5 | import time 6 | import ujson 7 | from utime import localtime, mktime 89 | # Setup SPI for the dual OLED display

### 10 spi = SPI

(

0, sck=Pin

(18), mosi=Pin

(19))

### 11 dc = Pin

(20

)

### 12 res = Pin

(21

)

### 13 cs1 = Pin

(17

)

### 14 cs2 = Pin

(

5

)
15
16 # Initialize the dual-screen OLED display

### 17 display = SSD1306_DualSPI

(256, 64, spi, dc, res, cs1, cs2) 18
19 # Initialize user interface buttons

### 20 btn_mode = Pin

(

0, Pin.IN, Pin.PULL_UP)

### 21 btn_select = Pin

(

3, Pin.IN, Pin.PULL_UP)

### 22 btn_up = Pin

(

6, Pin.IN, Pin.PULL_UP)

### 23 btn_down = Pin

(

7, Pin.IN, Pin.PULL_UP)
24
25 # Track button states for edge detection

### 26 last_button_state_btn_mode =

1

### 27 last_button_state_btn_select =

1

### 28 last_button_state_btn_up =

1

### 29 last_button_state_btn_down =

1
30
31 # UI and system state variables

### 32 mode =

0

### 33 edit_hour = True 34 flash_state = True 35 radio_info_toggle = False

36
37 # Default alarm and display settings

### 38 alarm_time = [

6, 30

]

### 39 alarm_active = False 40 snooze_minutes =

0

### 41 show_24hr = True 42 alarm_triggered = False 43 snooze_until = None

44
45 # Use a simulated clock that increments every second

### 46 sim_time = list(time.localtime()) 47 sim_last_tick = time.ticks_ms()

48
49 # Initialize FM radio once at 98.5 MHz

### 50 fm = Radio

(101.9,

2, False

)
51 #i2c_radio = I2C(1, scl=Pin(27), sda=Pin(26)) 52 # Alternate time zones (simulated)

### 53 alternate_timezones = [

54 ("UTC-12", -12.0),
55 ("UTC-11", -11.0),
56 ("UTC-10", -10.0),
57 ("UTC-09.5", -9.5),
58 ("UTC-09", -9.0),
59 ("UTC-08", -8.0),
60 ("UTC-07", -7.0),
61 ("UTC-06", -6.0),
62 ("UTC-05", -5.0),
63 ("UTC-04.5", -4.5),
64 ("UTC-04", -4.0),

/

5, 2:3

P

M

m

ain.p

y

file:///

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
dil.h

ml | 1

65 ("UTC-03.5", -3.5),
66 ("UTC-03", -3.0),
67 ("UTC-02", -2.0),
68 ("UTC-01", -1.0),
69 ("UTC+0", 0.0),
70 ("UTC+01", 1.0),
71 ("UTC+02", 2.0),
72 ("UTC+03", 3.0),
73 ("UTC+03.5", 3.5),
74 ("UTC+04", 4.0),
75 ("UTC+04.5", 4.5),
76 ("UTC+05", 5.0),
77 ("UTC+05.5", 5.5),
78 ("UTC+05.75", 5.75),
79 ("UTC+06", 6.0),
80 ("UTC+06.5", 6.5),
81 ("UTC+07", 7.0),
82 ("UTC+08", 8.0),
83 ("UTC+08.75", 8.75),
84 ("UTC+09", 9.0),
85 ("UTC+09.5", 9.5),
86 ("UTC+10:00", 10.0),
87 ("UTC+10.5", 10.5),
88 ("UTC+11", 11.0),
89 ("UTC+12", 12.0),
90 ("UTC+12.75", 12.75),
91 ("UTC+13", 13.0),
92 ("UTC+14", 14.0

)
93

]
94
95

### 96 selected_timezone_index =

0
97
98 # Path to settings file

### 99 SETTINGS_FILE = "settings.json"

100
101 # Attempt to load saved settings
102 try

:
103 with open(SETTINGS_FILE, "r") as f: 104 data = ujson.load(f)
105 alarm_time = data.get

("alarm_time", alarm_time)
106 alarm_active = data.get

("alarm_active", alarm_active)
107 snooze_minutes = data.get

("snooze_minutes", snooze_minutes) 108 show_24hr = data.get

("show_24hr", show_24hr)
109 except

:
110 pass
111
112 # Save settings to flash storage 113 def save_settings():
114 try

:
115 with open(SETTINGS_FILE, "w") as f: 116 ujson.dump({
117 "alarm_time": alarm_time,
118 "alarm_active": alarm_active, 119 "snooze_minutes": snooze_minutes, 120 "show_24hr": show_24hr
121 }, f)
122 except

:
123 pass
124
125 # Handle button press edge detection 126 def button_pressed(button, last_state): 127 current_state = button.value() 128 if last_state ==

1 and current_state ==

:
129 time.sleep

(0.05

)

130 if button.value() == 0: 131 return True, 0
132 return False, current_state 133
134 # Draw the main clock view 135 def draw_clock():
136 hour = sim_time[3]
137 minute = sim_time[4]
138 display.text("Freq: {:.1f}".format(fm.Frequency), 140, 10) 139 if not show_24hr:
140 suffix = "AM" if hour < 12 else "PM"
141 hour = hour % 12 or 12
142 display.text("Time: {:02d}:{:02d} {}".format(hour, minute, suffix), 10, 10) 143 else:
144 display.text("Time: {:02d}:{:02d}".format(hour, minute), 10, 10)
145 if alarm_active:
146 display.text("Alarm: {:02d}:{:02d}".format(*alarm_time), 140, 20) 147 display.text("Mode: Clock", 10, 50)
148
149 # Draw the alarm time setting view
150 def draw_alarm_set():
151 display.text("Set Alarm:", 10, 5)
152 display.text("Hour: {:02d}".format(alarm_time[0]), 140, 10) 153 display.text("Min : {:02d}".format(alarm_time[1]), 140, 50) 154 display.text("Mode: Alarm Set", 10, 50)
155
156 # Draw the FM radio interface
157 def draw_radio():
158 display.text("FM Radio", 10, 10)
159 display.text("Freq: {:.1f}".format(fm.Frequency), 140, 10) 160 if alarm_active:
161 display.text("A", 240, 0)
162 if radio_info_toggle:
163 display.text("Retro", 180, 20) 164 display.text("Mode: Radio", 10, 50) 165
166 # Draw the info/settings view
167 def draw_info():
168 display.text("Alarm: {:02d}:{:02d}".format(*alarm_time), 140, 10) 169 display.text("Snooze: +{}min".format(snooze_minutes), 140, 50) 170 display.text("Mode: Info", 10, 50)
171
172 # Draw the manual time change interface
173 def draw_time_change():
174 display.text("New Time: {:02d}:{:02d}".format(sim_time[3], sim_time[4]), 140, 10) 175 display.text("Edit: Hour" if edit_hour else "Edit: Minute", 140, 25)
176 display.text("Mode: Time Edit", 10, 50)
177
178 # Flashing display effect for alarm trigger
179 def draw_alarm_trigger():
180 global flash_state
181 flash_state = not flash_state
182 if flash_state:
183 display.text("!!! WAKE", 20, 15) 184 display.text("UP !!!", 140, 15)
185
186 # Time shifting for alternate timezones
187 def get_shifted_time(base_time, offset_hours):
188 shifted = base_time.copy()
189 total_minutes = shifted[3] * 60 + shifted[4] + int(offset_hours * 60) 190 total_minutes %= 1440
191 shifted[3] = total_minutes // 60
192 shifted[4] = total_minutes % 60
193 return shifted
194
7/30/25, 2:34 PM | main.py
file:///C:/Users/daryo/AppData/Roaming/Thonny/temp/thonny_hmlz1dil.html | 3/6

195 # Alternate timezone screen
196 def draw_alternate_timezones():
197 display.text("Alt Timezones:", 10, 5)
198 visible = alternate_timezones[selected_timezone_index:selected_timezone_index+2] 199 y_offset = 10
200 for label, offset in visible:
201 shifted = get_shifted_time(sim_time, offset)
202 display.text(f"{label}: {shifted[3]:02}:{shifted[4]:02}", 130, y_offset) 203 y_offset += 15
204 display.text("Mode: TZ View", 10, 50)
205
206 # Main loop
207 while True:
208 now_tick = time.ticks_ms()
209 if time.ticks_diff(now_tick, sim_last_tick) >= 1000: 210 sim_last_tick = now_tick
211 sim_time[5] += 1
212 if sim_time[5] >= 60:
213 sim_time[5] = 0
214 sim_time[4] += 1
215 if sim_time[4] >= 60:
216 sim_time[4] = 0
217 sim_time[3] += 1
218 if sim_time[3] >= 24:
219 sim_time[3] = 0
220
221 current_hour = sim_time[3]
222 current_minute = sim_time[4]
223 now_minutes = current_hour * 60 + current_minute
224 alarm_minutes = alarm_time[0] * 60 + alarm_time[1]
225 snooze_minutes_val = snooze_until[0] * 60 + snooze_until[1] if snooze_until else None 226
227 if alarm_active:
228 if snooze_until and now_minutes >= snooze_minutes_val:
229 snooze_until = None
230 if snooze_until is None and now_minutes == alarm_minutes: 231 alarm_triggered = True
232 elif alarm_triggered and now_minutes != alarm_minutes: 233 alarm_triggered = False
234
235 # Check all button presses at top of loop
236 pressed_mode, last_button_state_btn_mode = button_pressed(btn_mode, last_button_state_btn_mode) 237 pressed_select, last_button_state_btn_select = button_pressed(btn_select, last_button_state_btn_select)
238 pressed_up, last_button_state_btn_up = button_pressed(btn_up, last_button_state_btn_up)
239 pressed_down, last_button_state_btn_down = button_pressed(btn_down, last_button_state_btn_down) 240
241 display.fill(0)
242
243 if alarm_triggered:
244 draw_alarm_trigger()
245 if pressed_select:
246 alarm_triggered = False
247 if snooze_minutes > 0:
248 snooze_until = [current_hour, (current_minute + snooze_minutes) % 60] 249 if snooze_until[1] < current_minute:
250 snooze_until[0] = (snooze_until[0] + 1) % 24
251
252 else:
253 if pressed_mode:
254 mode = (mode + 1) % 6
255
256 if mode == 0:
257 draw_clock()
258 if pressed_select and alarm_triggered:
file:///C:/Users/daryo/AppData/Roaming/Thonny/temp/thonny_hmlz1dil.html | 4/6

259 alarm_triggered = False 260
261 elif mode ==

:
262 draw_radio()
263 if pressed_select:
264 radio_info_toggle = not radio_info_toggle 265
266 if pressed_up:
267 fm.Mute = True
268 fm.ProgramRadio()
269 new_freq = fm.Frequency + 0.2 270 if new_freq > 108

:
271 new_freq = 88.1
272 fm.SetFrequency(new_freq) 273 time.sleep

(0.1

)
274 fm.Mute = False
275 fm.ProgramRadio()
276
277 if pressed_down:
278 fm.Mute = True
279 fm.ProgramRadio()
280 new_freq = fm.Frequency - 0.2 281 if new_freq < 88

:
282 new_freq = 107.9
283 fm.SetFrequency(new_freq) 284 time.sleep

(0.1

)
285 fm.Mute = False
286 fm.ProgramRadio()
287
288 elif mode ==

2

:
289 draw_alarm_set()
290 if pressed_select:
291 alarm_active = not alarm_active 292 save_settings()
293
294 if pressed_up:
295 alarm_time[

0] = (alarm_time[

0] +

1) % 24
296 save_settings()
297
298 if pressed_down:
299 alarm_time[

1] = (alarm_time[

1] +

1) % 60
300 save_settings()
301
302 elif mode ==

3

:
303 draw_info()
304 if pressed_select:
305 snooze_minutes +=

5
306 if snooze_minutes > 30

:
307 snooze_minutes =

0
308 save_settings()
309
310 if pressed_up:
311 show_24hr = False
312 save_settings()
313
314 if pressed_down:
315 show_24hr = True
316 save_settings()
317
318 elif mode ==

4

:
319 draw_time_change()
320 if pressed_select:
321 edit_hour = not edit_hour 322
323 if pressed_up or pressed_down:

324 if edit_hour:
325 if pressed_up:
326 sim_time[3] = (sim_time[3] + 1) % 24 327 if pressed_down:
328 sim_time[3] = (sim_time[3] - 1) % 24 329 else:
330 if pressed_up:
331 sim_time[4] = (sim_time[4] + 1) % 60 332 if pressed_down:
333 sim_time[4] = (sim_time[4] - 1) % 60 334
335 if mode == 5:
336 draw_alternate_timezones()
337 if pressed_select:
338 selected_timezone_index += 1
339 if selected_timezone_index >= len(alternate_timezones): 340 selected_timezone_index = 0
341
342 display.show()
343 time.sleep(0.05)
344
file:///C:/Users/daryo/AppData/Roaming/Thonny/temp/thonny_hmlz1dil.html | 6/6

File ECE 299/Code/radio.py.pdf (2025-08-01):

1

### 2 from machine import Pin, I2C

3

### 4 class Radio: 5 def __init__(self, freq, vol, mute): 6 self.Volume = 2 7 self.Frequency = 88 8 self.Mute = False

9

### 10 self.SetVolume(vol) 11 self.SetFrequency(freq) 12 self.SetMute(mute)

13

### 14 self.i2c_sda = Pin(26) 15 self.i2c_scl = Pin(27) 16 self.i2c_device = 1 17 self.i2c_device_address = 0x10 18 self.Settings = bytearray(8) 19 self.radio_i2c = I2C(self.i2c_device, scl=self.i2c_scl, sda=self.i2c_sda, freq=200000) 20 self.ProgramRadio()

21

### 22 def SetVolume(self, v): 23 try: 24 v = int(v) 25 if 0 <= v < 16: 26 self.Volume = v 27 return True 28 except: 29 pass 30 return False

31

### 32 def SetFrequency(self, f): 33 try: 34 f = float(f) 35 if 88.0 <= f <= 108.0: 36 self.Frequency = f 37 return True 38 except: 39 pass 40 return False

41

### 42 def SetMute(self, m): 43 try: 44 self.Mute = bool(int(m)) 45 return True 46 except: 47 return False

48

### 49 def ComputeChannelSetting(self, f): 50 f = int(f * 10) - 870 51 return bytearray([(f >> 2) & 0xFF, ((f & 0x03) << 6) & 0xC0])

52

53 def UpdateSettings(self): 54 self.Settings[0] = 0x80 if self.Mute else 0xC0 55 self.Settings[1] = 0x09 | 0x04 56 self.Settings[2:4] = self.ComputeChannelSetting(self.Frequency) 57 self.Settings[3] |= 0x10 58 self.Settings[4] = 0x04 59 self.Settings[5] = 0x00 60 self.Settings[6] = 0x84 61 self.Settings[7] = 0x80 + self.Volume

62

### 63 def ProgramRadio(self): 64 self.UpdateSettings()

7/30/25, 2:40 PM | radio.py
file:///C:/Users/daryo/AppData/Roaming/Thonny/temp/thonny__lxhwz3r.html | 1/2

### 65 self.radio_i2c.writeto(self.i2c_device_address, self.Settings)

66

7/30/25, 2:40 PM | radio.py
file:///C:/Users/daryo/AppData/Roaming/Thonny/temp/thonny__lxhwz3r.html | 2/2

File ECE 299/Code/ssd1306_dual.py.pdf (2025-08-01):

1

### 2 from micropython import const 3 import framebuf 4 import time

5
6 # Register definitions

7 SET_CONTRAST = const(0x81) 8 SET_ENTIRE_ON = const(0xA4) 9 SET_NORM_INV = const(0xA6) 10 SET_DISP = const(0xAE) 11 SET_MEM_ADDR = const(0x20) 12 SET_COL_ADDR = const(0x21) 13 SET_PAGE_ADDR = const(0x22) 14 SET_DISP_START_LINE = const(0x40) 15 SET_SEG_REMAP = const(0xA0) 16 SET_MUX_RATIO = const(0xA8) 17 SET_IREF_SELECT = const(0xAD) 18 SET_COM_OUT_DIR = const(0xC0) 19 SET_DISP_OFFSET = const(0xD3) 20 SET_COM_PIN_CFG = const(0xDA) 21 SET_DISP_CLK_DIV = const(0xD5) 22 SET_PRECHARGE = const(0xD9) 23 SET_VCOM_DESEL = const(0xDB) 24 SET_CHARGE_PUMP = const(0x8D)

25

26 class SSD1306_DualSPI(framebuf.FrameBuffer): 27 def __init__(self, width, height, spi, dc, res, cs1, cs2, external_vcc=False): 28 self.width = width 29 self.height = height 30 self.external_vcc = external_vcc 31 self.pages = self.height // 8 32 self.buffer = bytearray(self.pages * self.width) 33 super().__init__(self.buffer, self.width, self.height, framebuf.MONO_VLSB)

34

### 35 self.spi = spi 36 self.dc = dc 37 self.res = res 38 self.cs1 = cs1 39 self.cs2 = cs2 40 self.rate = 10 * 1024 * 1024

41

### 42 for pin in (dc, res, cs1, cs2): 43 pin.init(pin.OUT, value=0)

44

### 45 self.reset() 46 self.init_display()

47

### 48 def reset(self): 49 self.res(1) 50 time.sleep_ms(1) 51 self.res(0) 52 time.sleep_ms(10) 53 self.res(1)

54

### 55 def write_cmd(self, cmd, cs): 56 self.spi.init(baudrate=self.rate, polarity=0, phase=0) 57 cs(1) 58 self.dc(0) 59 cs(0) 60 self.spi.write(bytearray([cmd])) 61 cs(1)

62

### 63 def write_data(self, buf, cs): 64 self.spi.init(baudrate=self.rate, polarity=0, phase=0)

7/30/25, 2:42 PM | ssd1306_dual.py
file:///C:/Users/daryo/AppData/Roaming/Thonny/temp/thonny_4yetpoqj.html | 1/3

### 65 cs(1) 66 self.dc(1) 67 cs(0) 68 self.spi.write(buf) 69 cs(1)

70

### 71 def init_display(self): 72 for cs in (self.cs1, self.cs2): 73 for cmd in (

74 SET_DISP,
75 SET_MEM_ADDR, 0x00,
76 SET_DISP_START_LINE,
77 SET_SEG_REMAP | 0x01,
78 SET_MUX_RATIO, self.height - 1,
79 SET_COM_OUT_DIR | 0x08,
80 SET_DISP_OFFSET, 0x00,
81 SET_COM_PIN_CFG, 0x02 if self.width > 2 * self.height else 0x12, 82 SET_DISP_CLK_DIV, 0x80,
83 SET_PRECHARGE, 0x22 if self.external_vcc else 0xF1,
84 SET_VCOM_DESEL, 0x30,
85 SET_CONTRAST, 0xFF,
86 SET_ENTIRE_ON,
87 SET_NORM_INV,
88 SET_IREF_SELECT, 0x30,
89 SET_CHARGE_PUMP, 0x10 if self.external_vcc else 0x14,
90 SET_DISP | 0x01,
91 ):

### 92 self.write_cmd(cmd, cs) 93 self.fill(0) 94 self.show()

95

### 96 def show(self): 97 for page in range(0, self.pages): 98 left_start = page * 256 99 right_start = left_start + 128

100
101 self.write_cmd(0xB0 | page, self.cs1)
102 self.write_cmd(0x00, self.cs1)
103 self.write_cmd(0x10, self.cs1)
104 self.write_data(self.buffer[left_start:left_start + 128], self.cs1) 105
106 self.write_cmd(0xB0 | page, self.cs2)
107 self.write_cmd(0x00, self.cs2)
108 self.write_cmd(0x10, self.cs2)
109 self.write_data(self.buffer[right_start:right_start + 128], self.cs2) 110
111 def poweroff(self):
112 for cs in (self.cs1, self.cs2):
113 self.write_cmd(SET_DISP, cs) 114
115 def poweron(self):
116 for cs in (self.cs1, self.cs2):
117 self.write_cmd(SET_DISP | 0x01, cs)
118
119 def contrast(self, contrast):
120 for cs in (self.cs1, self.cs2):
121 self.write_cmd(SET_CONTRAST, cs) 122 self.write_cmd(contrast, cs) 123
124 def invert(self, invert):
125 for cs in (self.cs1, self.cs2):
126 self.write_cmd(SET_NORM_INV | (invert & 1), cs)
127
128 def rotate(self, rotate):
129 for cs in (self.cs1, self.cs2):
file:///C:/Users/daryo/AppData/Roaming/Thonny/temp/thonny_4yetpoqj.html | 2/3

130 self.write_cmd(SET_COM_OUT_DIR | ((rotate & 1) << 3), cs)
131 self.write_cmd(SET_SEG_REMAP | (rotate & 1), cs)
132
file:///C:/Users/daryo/AppData/Roaming/Thonny/temp/thonny_4yetpoqj.html | 3/3

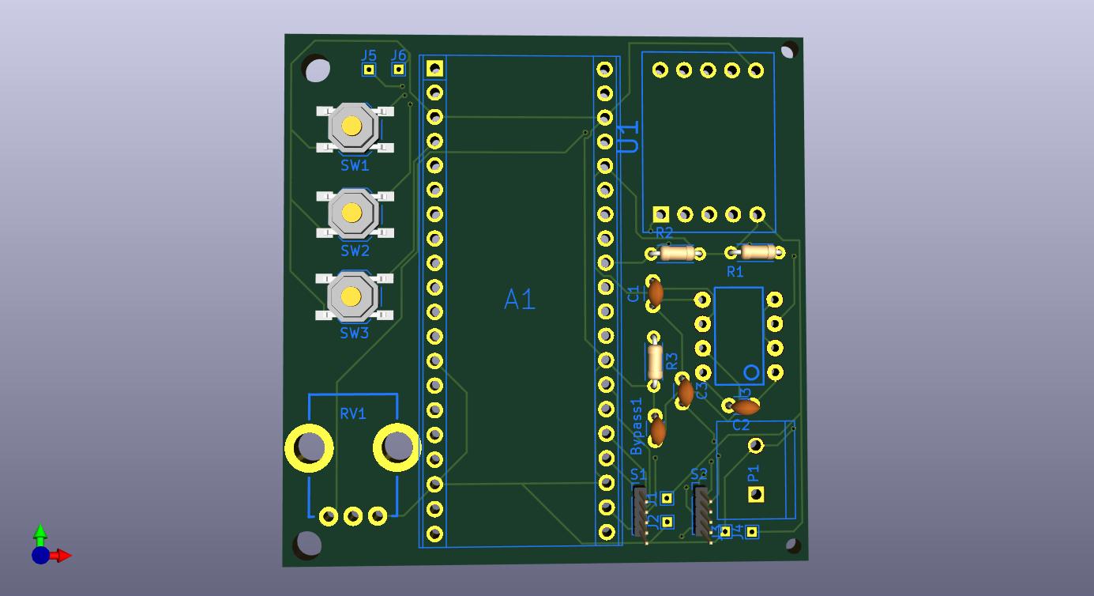
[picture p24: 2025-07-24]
ECE 299/ECE_299_Design/Clock-Radio_Prototype.jpg

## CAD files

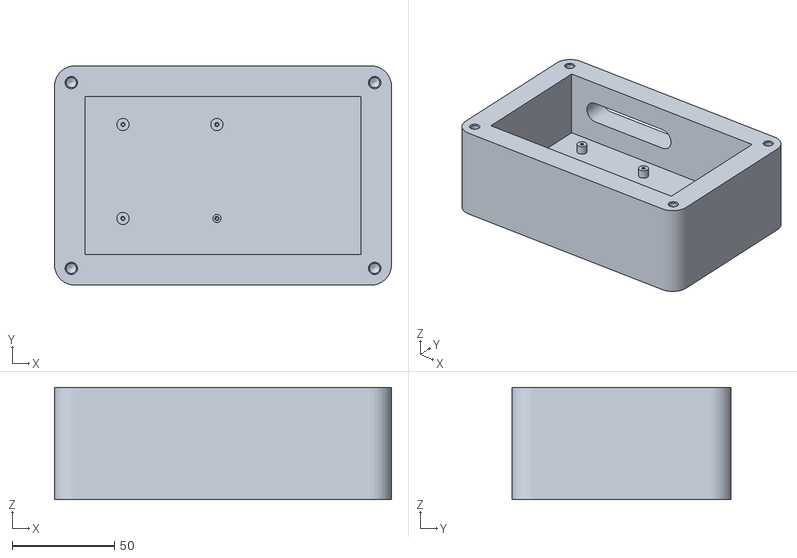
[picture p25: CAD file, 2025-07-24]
Bottom_Enclosure.STL
165.0 x 107.4 x 55.0

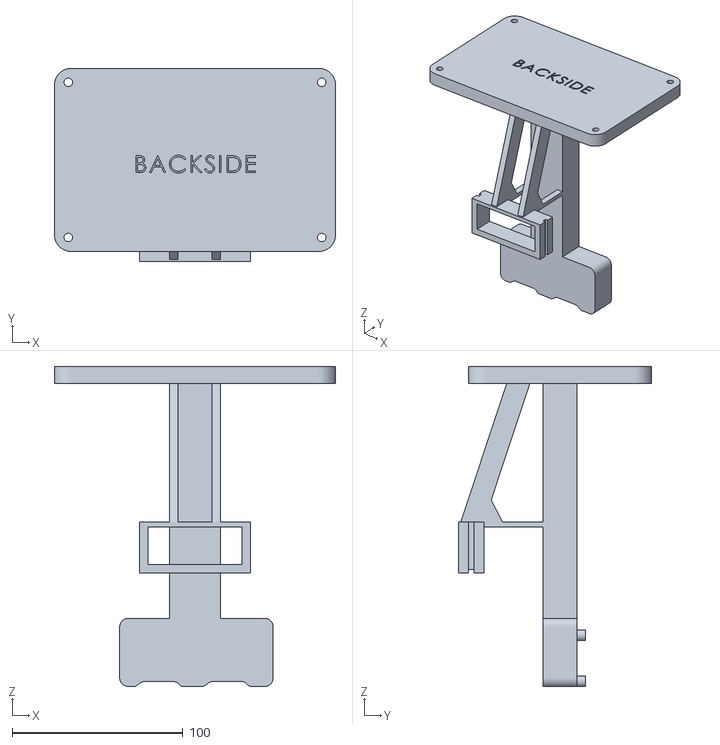
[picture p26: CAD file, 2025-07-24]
ECE 299/ECE_299_Design/Lid.STL
165.0 x 113.4 x 187.6

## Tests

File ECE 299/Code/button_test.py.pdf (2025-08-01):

1 # button_test.py

### 2 from machine import Pin 3 import time

4
5 # Define GPIO pins for the buttons

### 6 button_pins = [0, 3, 6, 7]

7
8 # Create Pin objects with internal pull-ups

### 9 buttons = [Pin(pin, Pin.IN, Pin.PULL_UP) for pin in button_pins] 10 last_states = [1] * len(buttons)

11

### 12 print("Button test running. Press any button...")

13

### 14 while True: 15 for i, btn in enumerate(buttons): 16 state = btn.value() 17 if state == 0 and last_states[i] == 1: # falling edge = button pressed 18 print(f"Button {i} (GPIO {button_pins[i]}) pressed") 19 last_states[i] = state 20 time.sleep(0.01)

21

7/30/25, 2:45 PM | button_test.py
file:///C:/Users/daryo/AppData/Roaming/Thonny/temp/thonny_1x05cvop.html | 1/1

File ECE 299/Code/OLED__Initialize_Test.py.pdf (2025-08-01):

### 1 from machine import Pin, SPI 2 from ssd1306_dual import SSD1306_DualSPI 3 from time

4
5 #Initialization
6

### 7 spi = SPI(0, sck=Pin(18), mosi=Pin(19)) 8 dc = Pin(20) 9 res = Pin(21) 10 cs1 = Pin(17) #screen 1 11 cs2 = Pin(5) #screen 2

12

### 13 display = SSD1306_DualSPI(256, 64, spi, dc, res, cs1, cs2)

14
15 #main
16

### 17 display.fill(0) 18 display.text("Time: "time.local_time, 0, 10) 19 display.text("Mode: Clock", 0, 30) 20 display.text("Freq: 98.5", 140, 10)

21

### 22 display.show()

7/30/25, 8:28 PM | OLED__Initialize_Test.py
file:///C:/Users/daryo/AppData/Roaming/Thonny/temp/thonny_qablufco.html | 1/1

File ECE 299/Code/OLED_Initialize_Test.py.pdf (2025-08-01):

### 1 from machine import Pin, SPI 2 from ssd1306_dual import SSD1306_DualSPI

3
4
5 #Initialization
6
7

### 8 spi = SPI(0, sck=Pin(18), mosi=Pin(19)) 9 dc = Pin(20) 10 res = Pin(21) 11 cs1 = Pin(17) # First screen

12 | cs2 = Pin(5) | # Second screen
13

### 14 display = SSD1306_DualSPI(256, 64, spi, dc, res, cs1, cs2)

15
16 ################################################################## 17
18 #main file for display
19

### 20 display.fill(0) 21 display.text("World", 130, 20) 22 display.text("Hello", 0, 20)

23

### 24 display.show()

25

7/30/25, 2:46 PM | OLED_Initialize_Test.py
file:///C:/Users/daryo/AppData/Roaming/Thonny/temp/thonny_nwz27wwo.html | 1/1

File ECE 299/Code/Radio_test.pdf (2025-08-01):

### 1 from machine import Pin, I2C 2 import time 3 import sys 4 import select

5
6 # Setup push button on GPIO 0 with pull-up resistor

### 7 button = Pin(0, Pin.IN, Pin.PULL_UP) 8 last_button_state = 1 # Start unpressed

9
10 # --- RADIO CLASS DEFINITION ---

### 11 class Radio: 12 def __init__(self, NewFrequency, NewVolume, NewMute): 13 self.Volume = 2 14 self.Frequency = 88 15 self.Mute = False

16

### 17 self.SetVolume(NewVolume) 18 self.SetFrequency(NewFrequency) 19 self.SetMute(NewMute)

20

### 21 self.i2c_sda = Pin(26) 22 self.i2c_scl = Pin(27)

23

### 24 self.i2c_device = 1 25 self.i2c_device_address = 0x10 26 self.Settings = bytearray(8)

27

### 28 self.radio_i2c = I2C(self.i2c_device, scl=self.i2c_scl, sda=self.i2c_sda, freq=200000) 29 self.ProgramRadio()

30

### 31 def SetVolume(self, NewVolume): 32 try: 33 NewVolume = int(NewVolume) 34 except: 35 return False 36 if not isinstance(NewVolume, int): 37 return False 38 if NewVolume < 0 or NewVolume >= 16: 39 return False 40 self.Volume = NewVolume 41 return True

42

### 43 def SetFrequency(self, NewFrequency): 44 try: 45 NewFrequency = float(NewFrequency) 46 except: 47 return False 48 if not isinstance(NewFrequency, float): 49 return False 50 if NewFrequency < 88.0 or NewFrequency > 108.0: 51 return False 52 self.Frequency = NewFrequency 53 return True

54

### 55 def SetMute(self, NewMute): 56 try: 57 self.Mute = bool(int(NewMute)) 58 except: 59 return False 60 return True

61

### 62 def ComputeChannelSetting(self, Frequency): 63 Frequency = int(Frequency * 10) - 870 64 ByteCode = bytearray(2)

7/30/25, 2:52 PM | <untitled> *
file:///C:/Users/daryo/AppData/Roaming/Thonny/temp/thonny_pqsaed80.html | 1/3

### 65 ByteCode[0] = (Frequency >> 2) & 0xFF 66 ByteCode[1] = ((Frequency & 0x03) << 6) & 0xC0 67 return ByteCode

68

69 def UpdateSettings(self): 70 self.Settings[0] = 0x80 if self.Mute else 0xC0 71 self.Settings[1] = 0x09 | 0x04 72 self.Settings[2:3] = self.ComputeChannelSetting(self.Frequency) 73 self.Settings[3] = self.Settings[3] | 0x10 74 self.Settings[4] = 0x04 75 self.Settings[5] = 0x00 76 self.Settings[6] = 0x84 77 self.Settings[7] = 0x80 + self.Volume

78

### 79 def ProgramRadio(self): 80 self.UpdateSettings() 81 self.radio_i2c.writeto(self.i2c_device_address, self.Settings)

82

### 83 def GetSettings(self): 84 self.RadioStatus = self.radio_i2c.readfrom(self.i2c_device_address, 256) 85 MuteStatus = not ((self.RadioStatus[0xF0] & 0x40) != 0x00) 86 VolumeStatus = self.RadioStatus[0xF7] & 0x0F

87 FrequencyStatus = ((self.RadioStatus[0x00] & 0x03) << 8) | (self.RadioStatus[0x01] & 0xFF)

### 88 FrequencyStatus = (FrequencyStatus * 0.1) + 87.0 89 StereoStatus = (self.RadioStatus[0x00] & 0x04) != 0x00 90 return MuteStatus, VolumeStatus, FrequencyStatus, StereoStatus

91
92
93 # --- MAIN PROGRAM STARTS HERE ---

### 94 fm_radio = Radio(101.9, 2, False)

95
96

### 97 def poll_button(fm_radio): 98 global last_button_state 99 current_state = button.value()

100 if last_button_state == 1 and current_state == 0: 101 print("Button Pressed: Increasing Volume") 102 if fm_radio.Volume < 15:
103 fm_radio.SetVolume(fm_radio.Volume + 1) 104 fm_radio.ProgramRadio()
105 print("Volume increased to", fm_radio.Volume) 106 else:
107 print("Volume already at max (15)")
108 time.sleep(0.5) # debounce
109 last_button_state = current_state
110
111
112 # --- Main interactive loop ---
113 while True:
114 print("\nECE 299 FM Radio Demo Menu") 115 print("1 - change radio frequency") 116 print("2 - change volume level") 117 print("3 - mute audio")
118 print("4 - read current settings") 119 print("Enter menu number > ", end="") 120
121 user_input = ""
122 while True:
123 poll_button(fm_radio)
124
125 ready = select.select([sys.stdin], [], [], 0) 126 if ready and sys.stdin in ready[0]:
127 user_input = sys.stdin.readline().strip()
128 break
129
file:///C:/Users/daryo/AppData/Roaming/Thonny/temp/thonny_pqsaed80.html | 2/3

130 time.sleep(0.05)
131
132 select_option = user_input 133
134 # --- Handle Menu Selection ---
135 if select_option == "1":
136 Frequency = input("Enter frequency in MHz (e.g., 100.3) > ") 137 if fm_radio.SetFrequency(Frequency):
138 fm_radio.ProgramRadio()
139 else:
140 print("Invalid frequency")
141
142 elif select_option == "2":
143 Volume = input("Enter volume level (0 to 15) > ") 144 if fm_radio.SetVolume(Volume):
145 fm_radio.ProgramRadio()
146 else:
147 print("Invalid volume")
148
149 elif select_option == "3":
150 Mute = input("Enter mute (1 for Mute, 0 for Audio) > ") 151 if fm_radio.SetMute(Mute):
152 fm_radio.ProgramRadio()
153 else:
154 print("Invalid mute setting") 155
156 elif select_option == "4":
157 Settings = fm_radio.GetSettings()
158 print("\nRadio Status")
159 print("Mute:", "enabled" if Settings[0] else "disabled") 160 print("Volume:", Settings[1])
161 print("Frequency: %5.1f MHz" % Settings[2])
162 print("Mode:", "stereo" if Settings[3] else "mono") 163 else:
164 print("Invalid option")
165
166 time.sleep(0.05)
file:///C:/Users/daryo/AppData/Roaming/Thonny/temp/thonny_pqsaed80.html | 3/3

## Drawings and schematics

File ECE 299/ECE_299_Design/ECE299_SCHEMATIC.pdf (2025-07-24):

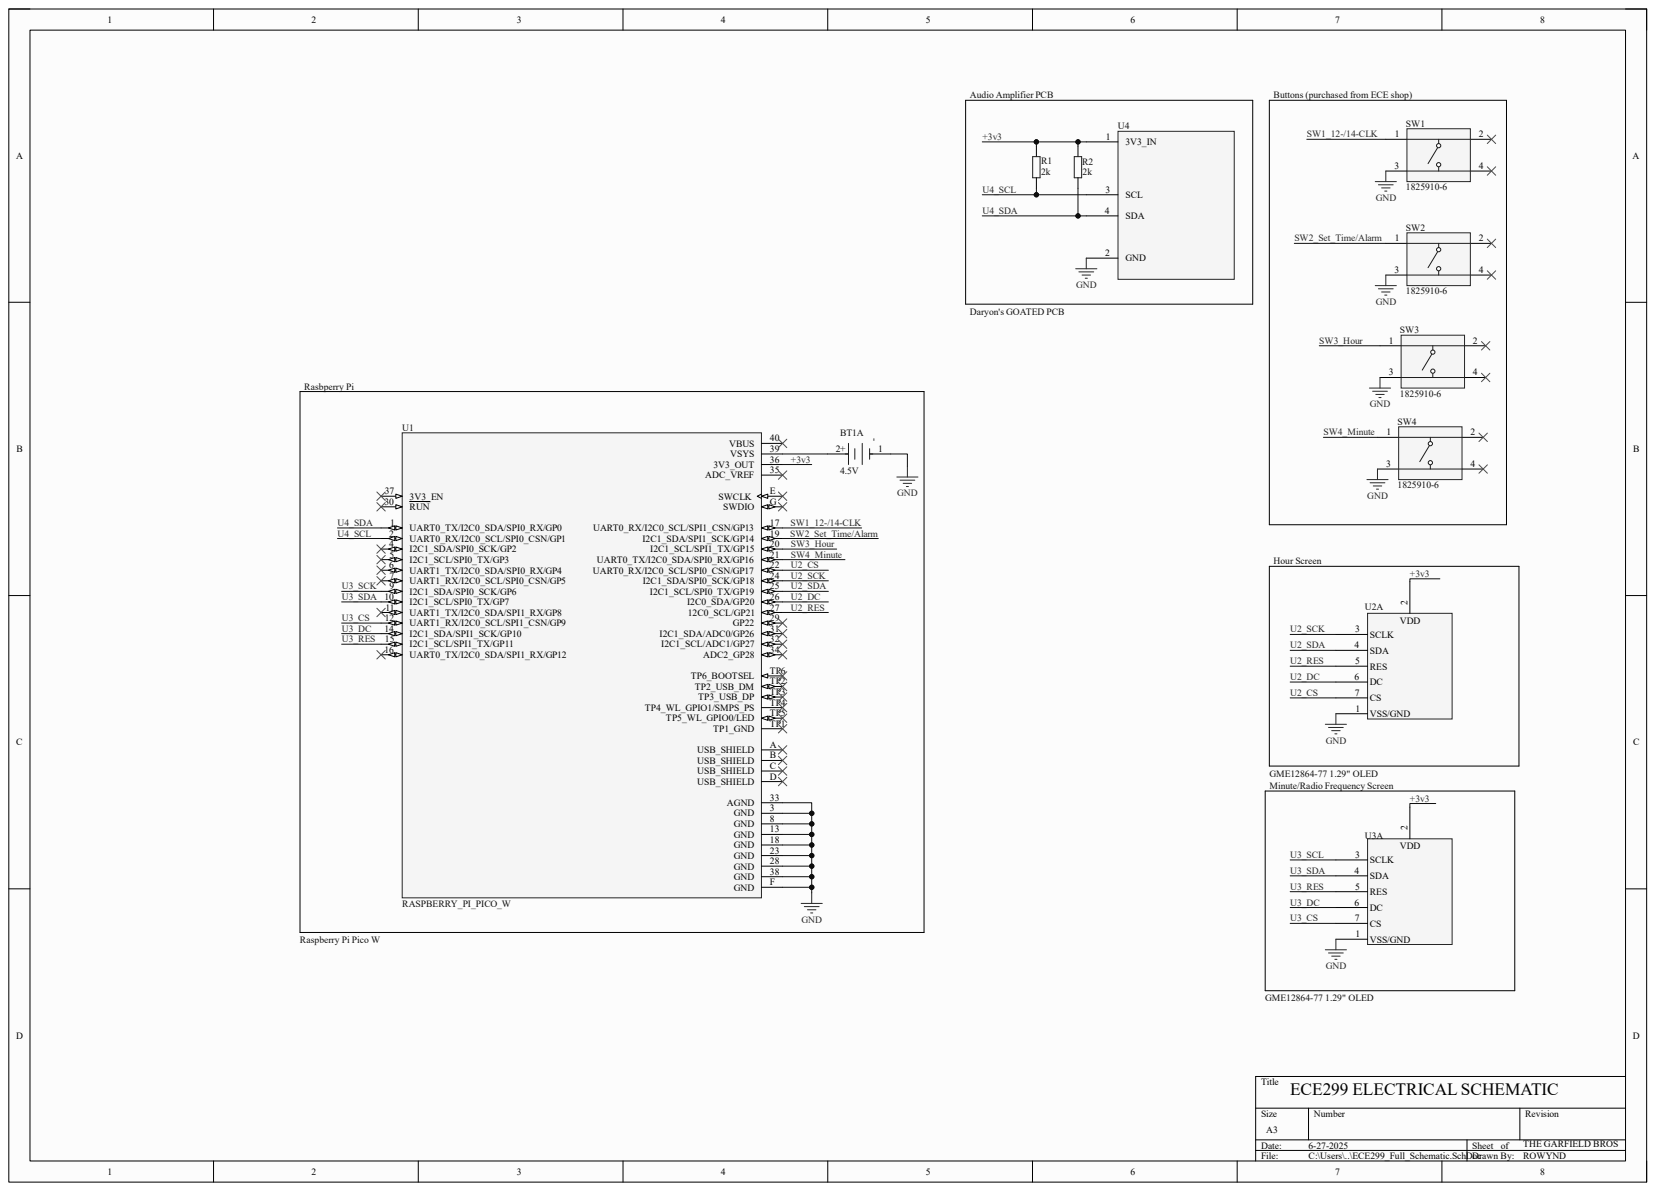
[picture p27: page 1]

Buttons (purchased from ECE shop)

GME12864-77 1.29" OLED
Minute/Radio Frequency Screen

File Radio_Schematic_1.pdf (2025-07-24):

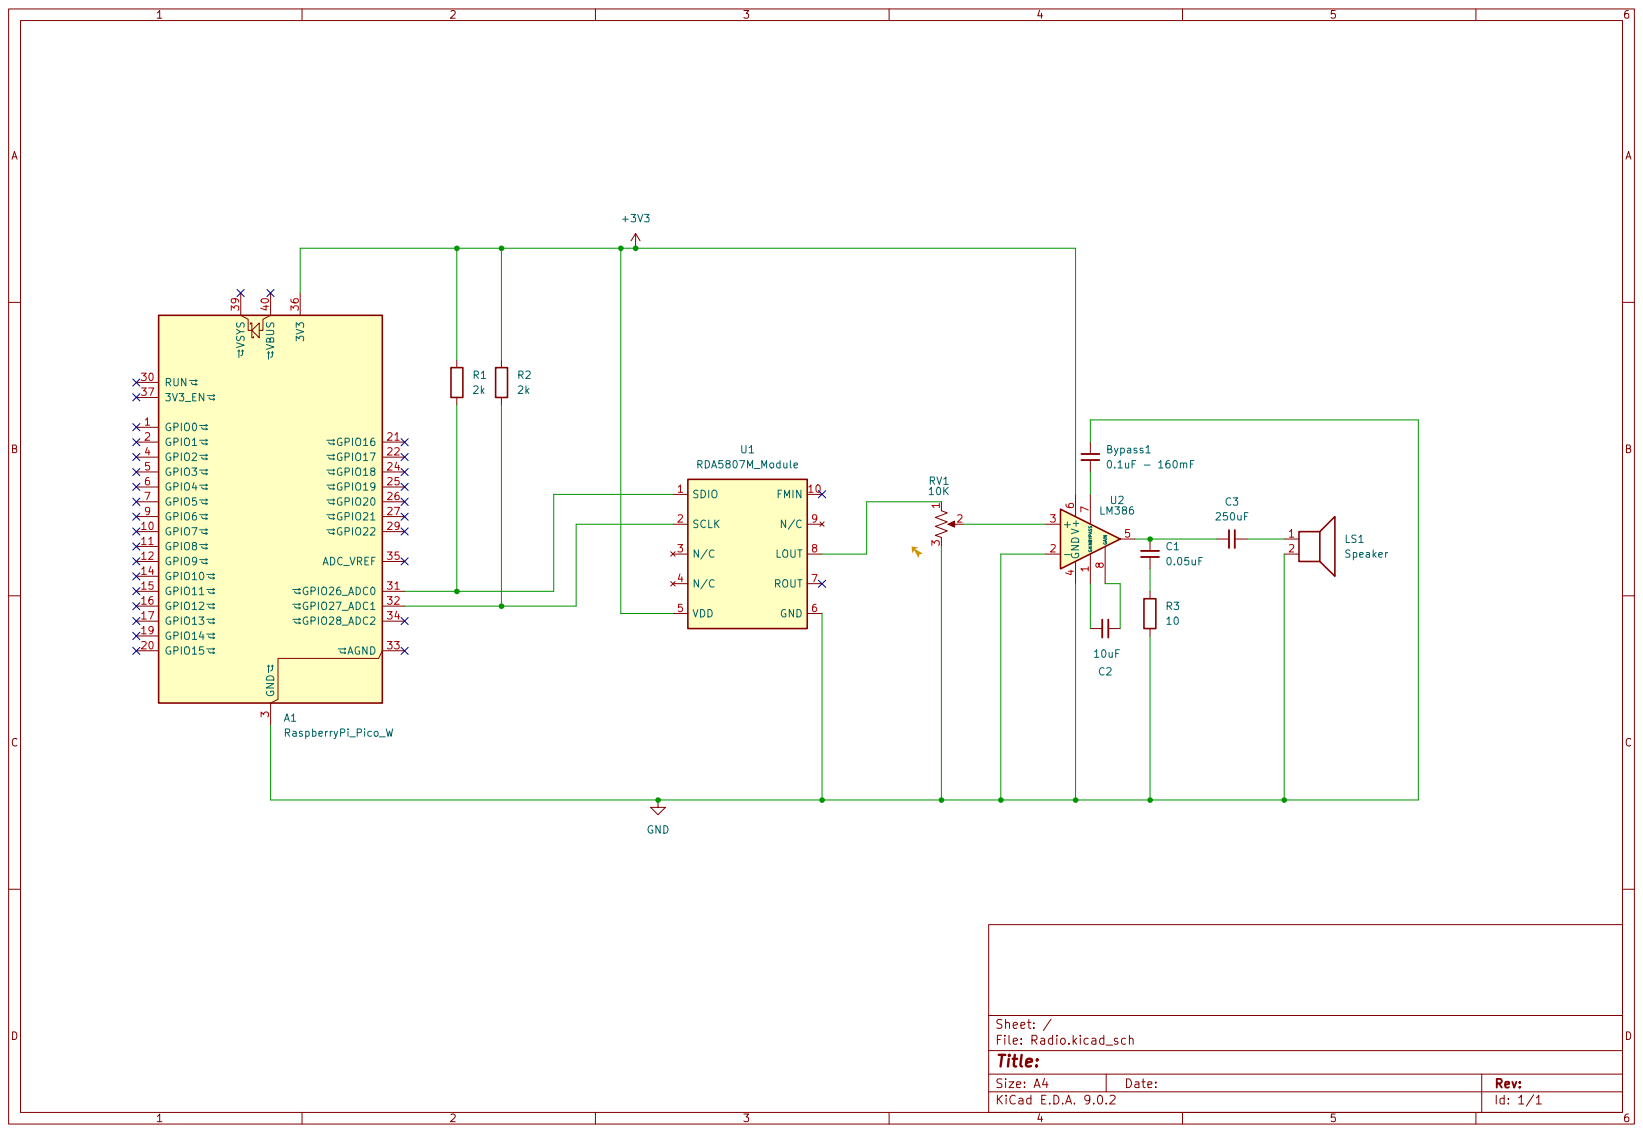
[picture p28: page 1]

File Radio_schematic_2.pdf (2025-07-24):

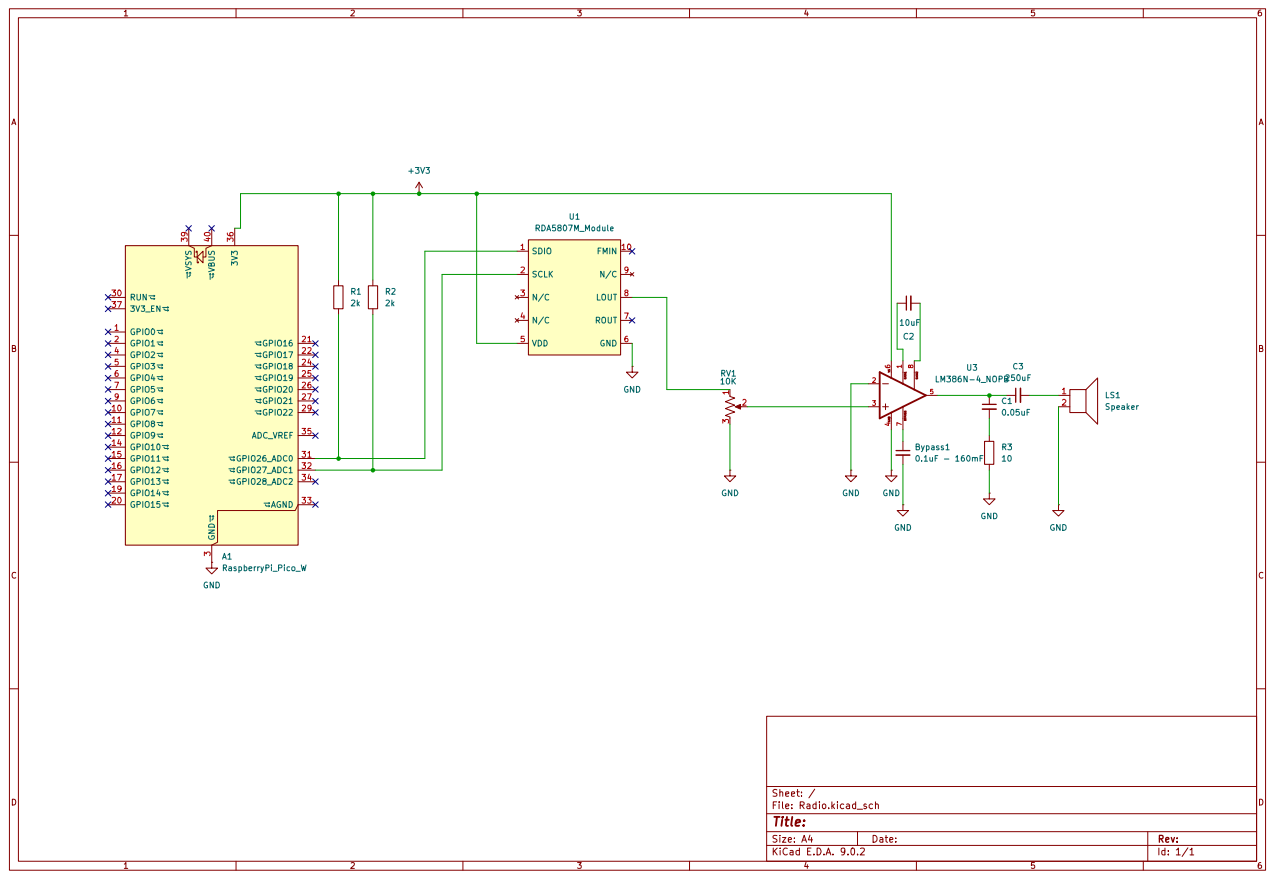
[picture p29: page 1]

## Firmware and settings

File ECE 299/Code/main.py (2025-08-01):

# Import necessary modules
from machine import Pin, SPI, I2C
from display import SSD1306_DualSPI
from radio import Radio
import time
import ujson
from utime import localtime, mktime

# Setup SPI for the dual OLED display
spi = SPI(0, sck=Pin(18), mosi=Pin(19))
dc = Pin(20)
res = Pin(21)
cs1 = Pin(17)
cs2 = Pin(5)

# Initialize the dual-screen OLED display
display = SSD1306_DualSPI(256, 64, spi, dc, res, cs1, cs2)

# Initialize user interface buttons
btn_mode = Pin(0, Pin.IN, Pin.PULL_UP)
btn_select = Pin(3, Pin.IN, Pin.PULL_UP)
btn_up = Pin(6, Pin.IN, Pin.PULL_UP)
btn_down = Pin(7, Pin.IN, Pin.PULL_UP)

# Track button states for edge detection
last_button_state_btn_mode = 1
last_button_state_btn_select = 1
last_button_state_btn_up = 1
last_button_state_btn_down = 1

# UI and system state variables
mode = 0
edit_hour = True
flash_state = True
radio_info_toggle = False

# Default alarm and display settings
alarm_time = [6, 30]
alarm_active = False
snooze_minutes = 0
show_24hr = True
alarm_triggered = False
snooze_until = None

# Use a simulated clock that increments every second
sim_time = list(time.localtime())
sim_last_tick = time.ticks_ms()

# Initialize FM radio once at 98.5 MHz
fm = Radio(101.9, 2, False)
#i2c_radio = I2C(1, scl=Pin(27), sda=Pin(26))
# Alternate time zones (simulated)
alternate_timezones = [
    ("UTC-12", -12.0),
    ("UTC-11", -11.0),
    ("UTC-10", -10.0),
    ("UTC-09.5", -9.5),
    ("UTC-09", -9.0),
    ("UTC-08", -8.0),
    ("UTC-07", -7.0),
    ("UTC-06", -6.0),
    ("UTC-05", -5.0),
    ("UTC-04.5", -4.5),
    ("UTC-04", -4.0),
    ("UTC-03.5", -3.5),
    ("UTC-03", -3.0),
    ("UTC-02", -2.0),
    ("UTC-01", -1.0),
    ("UTC+0", 0.0),
    ("UTC+01", 1.0),
    ("UTC+02", 2.0),
    ("UTC+03", 3.0),
    ("UTC+03.5", 3.5),
    ("UTC+04", 4.0),
    ("UTC+04.5", 4.5),
    ("UTC+05", 5.0),
    ("UTC+05.5", 5.5),
    ("UTC+05.75", 5.75),
    ("UTC+06", 6.0),
    ("UTC+06.5", 6.5),
    ("UTC+07", 7.0),
    ("UTC+08", 8.0),
    ("UTC+08.75", 8.75),
    ("UTC+09", 9.0),
    ("UTC+09.5", 9.5),
    ("UTC+10:00", 10.0),
    ("UTC+10.5", 10.5),
    ("UTC+11", 11.0),
    ("UTC+12", 12.0),
    ("UTC+12.75", 12.75),
    ("UTC+13", 13.0),
    ("UTC+14", 14.0)
]


selected_timezone_index = 0

# Path to settings file
SETTINGS_FILE = "settings.json"

# Attempt to load saved settings
try:
    with open(SETTINGS_FILE, "r") as f:
        data = ujson.load(f)
        alarm_time = data.get("alarm_time", alarm_time)
        alarm_active = data.get("alarm_active", alarm_active)
        snooze_minutes = data.get("snooze_minutes", snooze_minutes)
        show_24hr = data.get("show_24hr", show_24hr)
except:
    pass

# Save settings to flash storage
def save_settings():
    try:
        with open(SETTINGS_FILE, "w") as f:
            ujson.dump({
                "alarm_time": alarm_time,
                "alarm_active": alarm_active,
                "snooze_minutes": snooze_minutes,
                "show_24hr": show_24hr
            }, f)
    except:
        pass

# Handle button press edge detection
def button_pressed(button, last_state):
    current_state = button.value()
    if last_state == 1 and current_state == 0:
        time.sleep(0.05)
        if button.value() == 0:
            return True, 0
    return False, current_state

# Draw the main clock view
def draw_clock():
    hour = sim_time[3] 
    minute = sim_time[4]
    display.text("Freq: {:.1f}".format(fm.Frequency), 140, 10)
    if not show_24hr:
        suffix = "AM" if hour < 12 else "PM"
        hour = hour % 12 or 12
        display.text("Time: {:02d}:{:02d} {}".format(hour, minute, suffix), 10, 10)
    else:
        display.text("Time: {:02d}:{:02d}".format(hour, minute), 10, 10)
    if alarm_active:
        display.text("Alarm: {:02d}:{:02d}".format(*alarm_time), 140, 20)
    display.text("Mode: Clock", 10, 50)

# Draw the alarm time setting view
def draw_alarm_set():
    display.text("Set Alarm:", 10, 5)
    display.text("Hour: {:02d}".format(alarm_time[0]), 140, 10)
    display.text("Min : {:02d}".format(alarm_time[1]), 140, 50)
    display.text("Mode: Alarm Set", 10, 50)

# Draw the FM radio interface
def draw_radio():
    display.text("FM Radio", 10, 10)
    display.text("Freq: {:.1f}".format(fm.Frequency), 140, 10)
    if alarm_active:
        display.text("A", 240, 0)
    if radio_info_toggle:
        display.text("Retro", 180, 20)
    display.text("Mode: Radio", 10, 50)

# Draw the info/settings view
def draw_info():
    display.text("Alarm: {:02d}:{:02d}".format(*alarm_time), 140, 10)
    display.text("Snooze: +{}min".format(snooze_minutes), 140, 50)
    display.text("Mode: Info", 10, 50)

# Draw the manual time change interface
def draw_time_change():
    display.text("New Time: {:02d}:{:02d}".format(sim_time[3], sim_time[4]), 140, 10)
    display.text("Edit: Hour" if edit_hour else "Edit: Minute", 140, 25)
    display.text("Mode: Time Edit", 10, 50)

# Flashing display effect for alarm trigger
def draw_alarm_trigger():
    global flash_state
    flash_state = not flash_state
    if flash_state:
        display.text("!!! WAKE", 20, 15)
        display.text("UP !!!", 140, 15)

# Time shifting for alternate timezones
def get_shifted_time(base_time, offset_hours):
    shifted = base_time.copy()
    total_minutes = shifted[3] * 60 + shifted[4] + int(offset_hours * 60)
    total_minutes %= 1440
    shifted[3] = total_minutes // 60
    shifted[4] = total_minutes % 60
    return shifted

# Alternate timezone screen
def draw_alternate_timezones():
    display.text("Alt Timezones:", 10, 5)
    visible = alternate_timezones[selected_timezone_index:selected_timezone_index+2]
    y_offset = 10
    for label, offset in visible:
        shifted = get_shifted_time(sim_time, offset)
        display.text(f"{label}: {shifted[3]:02}:{shifted[4]:02}", 130, y_offset)
        y_offset += 15
    display.text("Mode: TZ View", 10, 50)

# Main loop
while True:
    now_tick = time.ticks_ms()
    if time.ticks_diff(now_tick, sim_last_tick) >= 1000:
        sim_last_tick = now_tick
        sim_time[5] += 1
        if sim_time[5] >= 60:
            sim_time[5] = 0
            sim_time[4] += 1
        if sim_time[4] >= 60:
            sim_time[4] = 0
            sim_time[3] += 1
        if sim_time[3] >= 24:
            sim_time[3] = 0

    current_hour = sim_time[3]
    current_minute = sim_time[4]
    now_minutes = current_hour * 60 + current_minute
    alarm_minutes = alarm_time[0] * 60 + alarm_time[1]
    snooze_minutes_val = snooze_until[0] * 60 + snooze_until[1] if snooze_until else None

    if alarm_active:
        if snooze_until and now_minutes >= snooze_minutes_val:
            snooze_until = None
        if snooze_until is None and now_minutes == alarm_minutes:
            alarm_triggered = True
        elif alarm_triggered and now_minutes != alarm_minutes:
            alarm_triggered = False

    # Check all button presses at top of loop
    pressed_mode, last_button_state_btn_mode = button_pressed(btn_mode, last_button_state_btn_mode)
    pressed_select, last_button_state_btn_select = button_pressed(btn_select, last_button_state_btn_select)
    pressed_up, last_button_state_btn_up = button_pressed(btn_up, last_button_state_btn_up)
    pressed_down, last_button_state_btn_down = button_pressed(btn_down, last_button_state_btn_down)

    display.fill(0)

    if alarm_triggered:
        draw_alarm_trigger()
        if pressed_select:
            alarm_triggered = False
            if snooze_minutes > 0:
                snooze_until = [current_hour, (current_minute + snooze_minutes) % 60]
                if snooze_until[1] < current_minute:
                    snooze_until[0] = (snooze_until[0] + 1) % 24

    else:
        if pressed_mode:
            mode = (mode + 1) % 6

        if mode == 0:
            draw_clock()
            if pressed_select and alarm_triggered:
                alarm_triggered = False

        elif mode == 1:
            draw_radio()
            if pressed_select:
                radio_info_toggle = not radio_info_toggle

            if pressed_up:
                fm.Mute = True
                fm.ProgramRadio()
                new_freq = fm.Frequency + 0.2
                if new_freq > 108:
                    new_freq = 88.1
                fm.SetFrequency(new_freq)
                time.sleep(0.1)
                fm.Mute = False
                fm.ProgramRadio()

            if pressed_down:
                fm.Mute = True
                fm.ProgramRadio()
                new_freq = fm.Frequency - 0.2
                if new_freq < 88:
                    new_freq = 107.9
                fm.SetFrequency(new_freq)
                time.sleep(0.1)
                fm.Mute = False
                fm.ProgramRadio()

        elif mode == 2:
            draw_alarm_set()
            if pressed_select:
                alarm_active = not alarm_active
                save_settings()

            if pressed_up:
                alarm_time[0] = (alarm_time[0] + 1) % 24
                save_settings()

            if pressed_down:
                alarm_time[1] = (alarm_time[1] + 1) % 60
                save_settings()

        elif mode == 3:
            draw_info()
            if pressed_select:
                snooze_minutes += 5
                if snooze_minutes > 30:
                    snooze_minutes = 0
                save_settings()

            if pressed_up:
                show_24hr = False
                save_settings()

            if pressed_down:
                show_24hr = True
                save_settings()

        elif mode == 4:
            draw_time_change()
            if pressed_select:
                edit_hour = not edit_hour

            if pressed_up or pressed_down:
                if edit_hour:
                    if pressed_up:
                        sim_time[3] = (sim_time[3] + 1) % 24
                    if pressed_down:
                        sim_time[3] = (sim_time[3] - 1) % 24
                else:
                    if pressed_up:
                        sim_time[4] = (sim_time[4] + 1) % 60
                    if pressed_down:
                        sim_time[4] = (sim_time[4] - 1) % 60

        if mode == 5:
            draw_alternate_timezones()
            if pressed_select:
                selected_timezone_index += 1
    if selected_timezone_index >= len(alternate_timezones):
        selected_timezone_index = 0

    display.show()
    time.sleep(0.05)

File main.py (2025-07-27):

from machine import Pin, SPI
from display import SSD1306_DualSPI
from radio import Radio
import time

# Setup SPI Display
spi = SPI(0, sck=Pin(18), mosi=Pin(19))
dc = Pin(20)
res = Pin(21)
cs1 = Pin(17)
cs2 = Pin(5)

display = SSD1306_DualSPI(256, 64, spi, dc, res, cs1, cs2)

# Setup buttons
btn_mode = Pin(0, Pin.IN, Pin.PULL_UP)
btn_select = Pin(1, Pin.IN, Pin.PULL_UP)
btn_up = Pin(2, Pin.IN, Pin.PULL_UP)
btn_down = Pin(3, Pin.IN, Pin.PULL_UP)

last_button_state_btn_mode = 1  # Start unpressed
last_button_state_btn_select = 1  # Start unpressed
last_button_state_btn_up = 1  # Start unpressed
last_button_state_btn_down = 1  # Start unpressed

last_mode = 1
mode = 0
alarm_time = [6, 30]  # 6:30 AM
alarm_active = False

# Setup radio
fm = Radio(101.9, 2, False)

def button_pressed(button, last_state):
    current_state = button.value()
    if last_state == 1 and current_state == 0:
        time.sleep(0.05)
        if button.value() == 0:
            return True, 0
    return False, current_state

def draw_clock():
    now = time.localtime()
    display.text("Time: {:02d}:{:02d}".format(now[3], now[4]), 10, 10)
    if alarm_active:
        display.text("Alarm: {:02d}:{:02d}".format(*alarm_time), 140, 10)
        display.text("Mode: Clock", 10, 50)

def draw_alarm_set():
    display.text("Set Alarm:", 10, 10)
    display.text("Hour: {:02d}".format(alarm_time[0]), 10, 30)
    display.text("Min : {:02d}".format(alarm_time[1]), 140, 30)
    display.text("Mode: Alarm Set", 10, 50)

def draw_radio():
    display.text("FM Radio", 10, 10)
    display.text("Freq: {:.1f}".format(fm.Frequency), 10, 30)
    display.text("Vol: {}".format(fm.Volume), 140, 30)
    display.text("Mode: Radio", 10, 50)

while True:
    # Mode button
    
    print(mode)
    
    mode = 0

    pressed_mode, last_button_state_btn_mode = button_pressed(btn_mode, last_button_state_btn_mode)
    if pressed_mode:
        mode = (mode + 1)  # Cycle through 0 to 3
        if mode > 3:
            mode = 0

    display.fill(0)

    if mode == 0:  # Clock
        draw_clock()
        print(mode)


    elif mode == 1:  # Alarm Set
        draw_alarm_set()

        pressed_up, last_button_state_btn_up = button_pressed(btn_up, last_button_state_btn_up)
        pressed_down, last_button_state_btn_down = button_pressed(btn_down, last_button_state_btn_down)
        
        if pressed_up and last_button_state_btn_up:
            alarm_time[0] = (alarm_time[0] + 1) % 24
            time.sleep(0.2)

        if pressed_down and last_button_state_btn_down:
            alarm_time[1] = (alarm_time[1] + 1) % 60
            time.sleep(0.2)

        if button_pressed(btn_select, last_button_state_btn_select)[0]:
            alarm_active = not alarm_active
            time.sleep(0.2)


    elif mode == 2:  # Radio
        draw_radio()
        if button_pressed(btn_up, last_button_state_btn_up)[0]:
            fm.SetVolume((fm.Volume + 1) % 16)
            fm.ProgramRadio()
            time.sleep(0.2)
        if button_pressed(btn_down, last_button_state_btn_down)[0]:
            fm.SetVolume((fm.Volume - 1) % 16)
            fm.ProgramRadio()
            time.sleep(0.2)


    elif mode == 3:  # Alarm check
        now = time.localtime()
        if alarm_active and (now[3], now[4]) == tuple(alarm_time):
            display.text("WAKE UP!", 80, 25)
        else:
            display.text("No Alarm Now", 80, 25)

    display.show()
    time.sleep(0.05)

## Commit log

2025-06-10 changed pin 26 to pin 24
2025-06-10 Revert "changed pin 26 to pin 24"
    This reverts commit c5ec2d0211915ad1d64694394bd3ca08a0a284b2.
    [fm_radio.py]
2025-06-12 Updated code for FM radio
    Adds a button which increases the volume on every press.
2025-06-23 Add files via upload
    Initial Radio and Amplifier circuit for a gain of 200 (~46dB)
    [Radio.kicad_pcb, Radio.kicad_sch]
2025-06-23 Add files via upload
    Updated Schematic of Radio and Amplifier circuit with 200 gain and proper footprints
2025-06-24 Add files via upload
    updated schematic and board design with traces for Radio and Amplifier. V2
    [Radio.kicad_pcb, Radio.kicad_sch]
2025-06-26 Add files via upload
    Could be this
    [Sheet1.SchDoc]
2025-06-27 3D prototype jpeg
2025-07-05 Final PCB Design
    Complete PCB Design for Clock-Radio Project
    Includes:
    - Backup Files
    - Schematics
    - PCB Editor
    - 3D view .jpg
    [Clock-Radio.kicad_pcb, Clock-Radio.kicad_sch]
2025-08-01 Complete Project Folder
    Completion of the project "Clock-Radio" (informally referred by the team as "George") for the class ECE 299 at the University of Victoria by students Daryon Ambasse and Rowyn Davis. Folder includes:
    1) Complete main code
    2) Testing modules
    3) Complete documentation of the design process
    4) PCB schematic updates and 3D design files
    5) Micropython boot files
    [Clock-Radio.kicad_pcb, Clock-Radio.kicad_sch, Lid.STL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]
